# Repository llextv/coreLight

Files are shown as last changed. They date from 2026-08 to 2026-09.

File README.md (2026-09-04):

# CoreLight

CoreLight is an open-source DIY lighting controller built around an STM32H743.

The project is designed to manage stage lighting systems with up to **13 DMX universes**, Ethernet protocols such as **Art-Net and sACN**, timecode synchronization, show playback and system monitoring.

The goal is not to recreate a grandMA3 console. CoreLight is intended to be a hardware platform for a future open-source lighting-control system.

## Main features

- Up to 13 DMX outputs
- DMX512 and RS-485 communication
- Art-Net and sACN support
- Planned RDM support
- LTC and MTC timecode
- Show recording and playback
- Standalone operation
- DMX routing and merging
- Failover and redundancy
- Ethernet and OSC control
- Internal web interface
- Temperature, power and fan monitoring
- MicroSD and Flash storage
- USB-C for programming and updates
- RTC with battery backup
- Custom 4-layer PCB
- 3D-printed rack-mount enclosure

Most of these features are still under development. The current version should be considered a hardware prototype rather than a finished lighting controller.

---

## Architecture

The STM32H743 is the central processor of the system. It handles network communication, timecode, DMX processing, show playback and system monitoring.

The controller can also receive LTC, MTC and external event inputs. Lighting data is processed by the STM32 and sent to the required DMX outputs.

---

## Hardware

The current design uses the following main components:

| Component | Function |
|---|---|
| **STM32H743ZIT6** | Main microcontroller |
| **W5500** | Ethernet interface |
| **MAX3485** | DMX / RS-485 transceivers |
| **CD74HC4067M** | Signal routing and multiplexing |
| **IS42S16400J-7TL** | External SDRAM |
| **W25Q128JVSIQ** | SPI Flash |
| **DS3231M+** | Real-time clock |
| **INA226AIDGST** | Power monitoring |
| **TMP117AIDRVR** | Temperature monitoring |
| **SM712** | DMX transient protection |
| **USBLC6-2SC6** | USB ESD protection |

The complete component list is available in [BOM.csv](BOM.csv).

---

## Processing and memory

The STM32H743 was selected because the project requires more processing power and memory bandwidth than a basic microcontroller-based DMX interface.

It is responsible for:

- Art-Net, sACN and OSC communication
- DMX universe management
- RDM and DMX monitoring
- Show playback
- Timecode processing
- Failover logic
- Fan and thermal management
- System logs and diagnostics

### External SDRAM

The external SDRAM is used for temporary runtime data such as:

- DMX buffers
- Network packets
- Show playback data
- Large processing structures

### SPI Flash

The W25Q128JVSIQ Flash can be used for firmware, configuration and persistent system data.

### MicroSD card

The microSD card is intended for user-accessible files:

```text
/show
/config
/logs
/firmware
```

Shows, configuration files, logs and firmware updates can be stored on the card.

---

## DMX

CoreLight is designed to support up to **13 DMX universes**.

Each output uses a MAX3485 RS-485 transceiver and includes transient protection. A DMX universe contains up to 512 channels, giving a theoretical total of:

\[
13 \times 512 = 6656 \text{ DMX channels}
\]

Standard DMX wiring is used

The DMX data rate is 250 kbit/s.

Planned DMX features include:

- Flexible universe routing
- DMX repeater mode
- RDM
- DMX monitoring
- Signal-loss detection
- DMX merging and failover

For example, one network universe could be sent to several physical outputs

---

## Art-Net, sACN and Ethernet

Ethernet communication is handled by the W5500.

The network interface is intended to support:

- Art-Net
- sACN
- OSC
- Web-based configuration and monitoring

Network universes can be mapped to any of the physical DMX outputs instead of being permanently assigned to a single port.

---

## Timecode

CoreLight includes an LTC input and is designed to support MTC.

Timecode can be used to trigger lighting events or control show playback:

Example events could include scene changes, effect triggers or the start of a complete lighting sequence.

The RTC is used for system time, logs and scheduled events. It is separate from LTC, which is used for show synchronization.

---

## Standalone playback

A show can be uploaded to the microSD card and played back without a permanent computer connection.

A show file may contain:

- Scenes
- Cues
- DMX values
- Timing information
- Events
- Timecode positions

During playback, the STM32 loads the required data and generates the DMX output in real time.

---

## Failover and DMX merging

One of the main objectives is to improve system reliability during shows.

CoreLight is intended to detect problems such as:

- Loss of network data
- Software or hardware failure
- Missing DMX input
- Communication errors

Depending on the final firmware, the controller could switch to a backup source or continue playback using a locally stored show.

DMX merging is also planned, allowing several sources to contribute to the same output:

The merging rules and failover behavior are still being designed.

---

## Monitoring and cooling

The system includes temperature and power monitoring using a TMP117 and an INA226.

The firmware will be able to control the cooling fan and warn the user in case of excessive temperature or abnormal power consumption.

Available hardware includes:

- Temperature sensor
- Power monitor
- Fan output
- Status LEDs
- Buzzer

---

## Power supply

The controller is designed for a 24 V DC input.

The regulated voltages power the STM32, Ethernet interface, DMX transceivers, sensors and other logic circuits.

---

## User interface and web interface

The initial local interface consists of:

- Rotary encoder
- Push buttons
- Status LEDs
- Buzzer

A future web interface will provide access to:

- System status
- DMX monitoring
- Network settings
- Show management
- Logs
- Temperature and power data
- Firmware updates

The controller is intended to be configurable from a browser without requiring a dedicated screen.

Software link for the moment: 
https://www.qlcplus.org/download#

---

## PCB and enclosure

The PCB was designed in KiCad and uses four layers to simplify routing and provide dedicated ground and power planes.

The board contains:

- STM32H743
- External SDRAM
- SPI Flash
- Ethernet
- 13 DMX interfaces
- LTC input
- USB-C
- MicroSD
- RTC
- Power regulation
- Monitoring circuits
- User interface connections

The current design contains approximately 192 footprints.

The enclosure is a custom 3D-printed rack-mount case with openings for the DMX outputs, Ethernet, USB-C, LTC, power, fan and user controls.

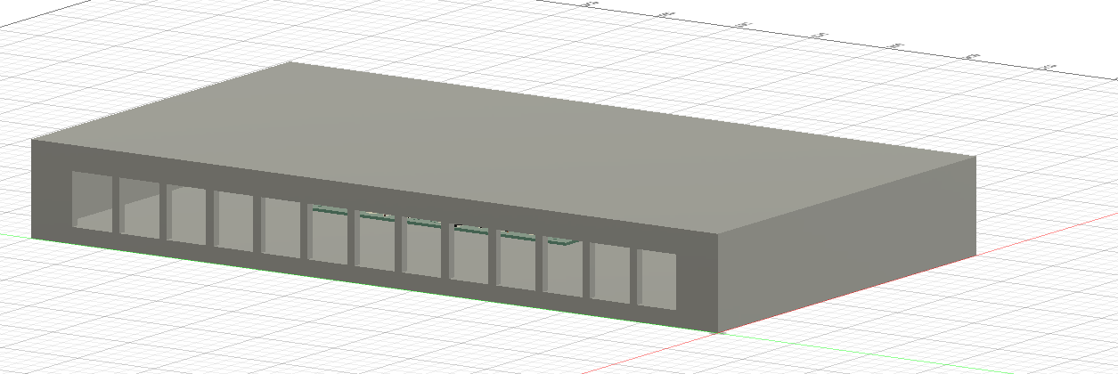
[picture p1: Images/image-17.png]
CoreLight enclosure


Assembly file: [coreLightAssembly.step](cad/coreLightAssembly.step)

CAD files are available in:

```text
/cad
```

The complete KiCad schematic is available in:

```text
/scheme
```
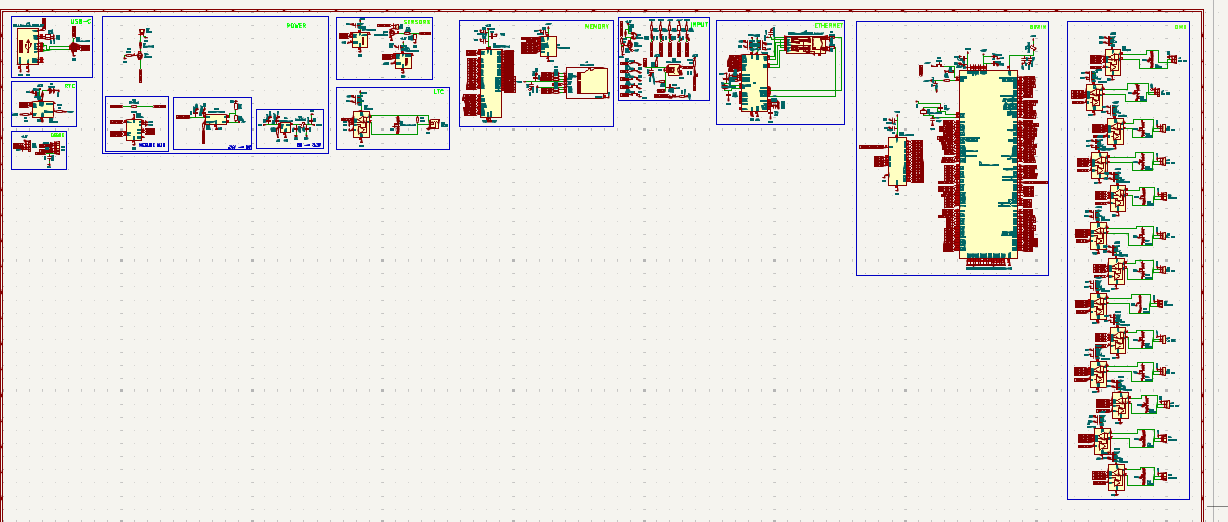
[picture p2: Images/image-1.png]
Scheme


---

## Estimated cost

The current estimate is:

```text
Components:  $66.01
PCB:         $36.99
Total:      ~$103 USD
```

This does not include shipping, assembly, enclosure parts or future design changes.

---

## Project journal

The development process is documented in [JOURNAL.md](JOURNAL.md).

It includes the PCB design, STM32CubeMX configuration, KiCad work, enclosure design, BOM creation and the problems encountered during development.

---

## Inspiration

CoreLight was inspired by professional lighting hardware such as the grandMA3 Processing Unit and Replay Unit.

The project is independent and is not affiliated with MA Lighting.

- [MA Lighting grandMA3 Processing Unit](https://www.malighting.com/product/grandma3-processing-unit-m-4010510/)
- [MA Lighting grandMA3 Replay Unit](https://www.malighting.com/product/grandma3-replay-unit-4010507/)

---

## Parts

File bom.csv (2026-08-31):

Category / Component | Manufacturer Part / Type | Quantity | Unit Price (USD) | Total Price (USD) | LCSC Link
Microcontroller | STM32H743ZIT6 | 1 | 15.50 | 15.50 | https://www.lcsc.com/category/941.html
Ethernet Controller | W5500 | 1 | 2.15 | 2.15 | https://www.lcsc.com/product-detail/C32843.html
DMX Transceiver | MAX3485ESA+ | 14 | 0.45 | 6.30 | https://www.lcsc.com/product-detail/C22447116.html
Multiplexer | CD74HC4067M | 1 | 0.32 | 0.32 | https://www.lcsc.com/product-detail/C496123.html
RTC | DS3231M+ | 1 | 1.80 | 1.80 | https://www.lcsc.com/product-detail/C1520508.html
SDRAM | IS42S16400J-7TL | 1 | 1.20 | 1.20 | https://www.lcsc.com/product-detail/C94865.html
SPI Flash | W25Q128JVSIQ | 1 | 0.75 | 0.75 | https://www.lcsc.com/product-detail/C113767.html
3.3V Regulator | AP2112K-3.3 | 1 | 0.22 | 0.22 | https://www.lcsc.com/product-detail/C23380830.html
5V Regulator | LM2596S-ADJ | 1 | 0.45 | 0.45 | https://www.lcsc.com/product-detail/C194351.html
Power Monitor | INA226AIDGST | 1 | 1.10 | 1.10 | https://www.lcsc.com/product-detail/C2653870.html
Temperature Sensor | TMP117AIDRVR | 1 | 1.40 | 1.40 | https://www.lcsc.com/product-detail/C699536.html
USB ESD Protection | USBLC6-2SC6 | 1 | 0.08 | 0.08 | https://www.lcsc.com/product-detail/C5261088.html
DMX TVS Protection | SM712 | 13 | 0.15 | 1.95 | https://www.lcsc.com/product-detail/C908219.html
Schottky Diode | 1N5819 | 1 | 0.03 | 0.03 | https://www.lcsc.com/product-detail/C2474.html
Switching Diode | 1N4148 | 1 | 0.01 | 0.01 | https://www.lcsc.com/product-detail/C49318123.html
Capacitor 100nF (0805) | 0805 X7R 50V 100nF | 33 | 0.005 | 0.17 | https://www.lcsc.com/product-detail/C49678.html
Capacitor 4.7µF (0805) | 0805 X5R 25V 4.7µF | 23 | 0.01 | 0.23 | https://www.lcsc.com/product-detail/C1779.html
Capacitor 22pF (0805) | 0805 C0G 50V 22pF | 4 | 0.005 | 0.02 | https://www.lcsc.com/product-detail/C1804.html
Resistor 10k (0805) | 0805 1% 1/8W 10k | 15 | 0.004 | 0.06 | https://www.lcsc.com/product-detail/C2907219.html
Resistor 330R (0805) | 0805 1% 1/8W 330R | 9 | 0.004 | 0.04 | https://www.lcsc.com/product-detail/C17630.html
Resistor 120R (0805) | 0805 1% 1/8W 120R | 1 | 0.004 | 0.004 | https://www.lcsc.com/product-detail/C17437.html
RJ45 Connector | HR911105A | 1 | 0.85 | 0.85 | https://www.lcsc.com/product-detail/C12074.html
MicroSD Connector | DM3D-SF | 1 | 0.30 | 0.30 | https://www.lcsc.com/product-detail/C719027.html
USB-C Connector | USB-C 16P (SMD) | 1 | 0.18 | 0.18 | https://www.lcsc.com/product-detail/C165948.html
24V Terminal Block | Phoenix 5.08mm 2P | 1 | 0.15 | 0.15 | https://www.lcsc.com/product-detail/C5183929.html
JST XH Connectors | JST-XH 2P/3P/4P/5P | 15 | 0.05 | 0.75 | https://www.lcsc.com/product-detail/C144394.html
3.5mm Audio Jack | Audio Jack 3.5mm (LTC) | 1 | 0.12 | 0.12 | https://www.lcsc.com/product-detail/C49284723.html
Rotary Encoder | EC11 with Switch | 1 | 0.25 | 0.25 | https://www.lcsc.com/product-detail/C2991196.html
Push Buttons | Tactile Switch 6x6mm | 6 | 0.03 | 0.18 | https://www.lcsc.com/product-detail/C7528752.html
Buzzer | Buzzer 3.3V | 1 | 0.10 | 0.10 | https://www.lcsc.com/product-detail/C252915.html
Battery Holder | CR2032 Battery Holder | 1 | 0.20 | 0.20 | https://www.lcsc.com/product-detail/C964792.html
Crystal Quartz | Crystal 25MHz (3225) | 2 | 0.08 | 0.16 | https://www.lcsc.com/product-detail/C9006.html
Transistor | 2N7002 | 1 | 0.011 | 0.011 | https://www.lcsc.com/product-detail/C916396.html
Resettable Fuse | 2920L500/30GR | 1 | 0.15 | 0.15 | https://www.lcsc.com/product-detail/C19078763.html

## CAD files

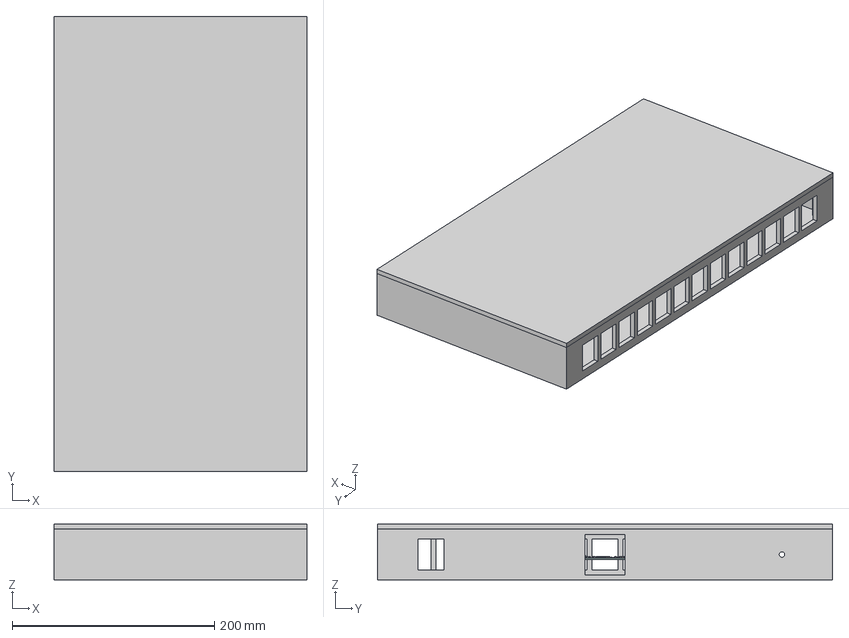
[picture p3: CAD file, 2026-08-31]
cad/coreLightAssembly.step
250.0 x 450.0 x 55.0 mm
D_DO-41_SOD81_P10.16mm_Horizontal_1
C_0805_2012Metric_1 x 69
R_0805_2012Metric_1 x 38
SOIC_8_39x49mm_P127mm x 14
JST_B3B_XH_A x 13
WSON_6_1EP_2x2mm_P065mm_EP1x16mm x 2
Keystone_3000_1x12mm
SOT_23_1 x 14
SOIC_24W_75x154mm_P127mm
JST_B4B_XH_A
Buzzer_12x95RM76
SOIC_16W_75x103mm_P127mm
SOT_23
LED_0805_2012Metric_1 x 7
microSD_HC_Hirose_DM3D-SF_1
VSSOP_10_3x3mm_P05mm
D_DO-35_SOD27_P7.62mm_Horizontal_1
TerminalBlock_Phoenix_MKDS_15_2_508_1x02_P508mm_Horizontal
Crystal_SMD_3225-4Pin_3.2x2.5mm_1 x 2
CQ assembly_1 x 2
CQ assembly
JST_B2B_XH_A
TSOP_II_54_222x1016mm_P08mm
JST_B5B_XH_A
LQFP_48_7x7mm_P05mm
SOT_23_5
SOT_23_6
coreLight_PCB
coreLightTop
coreLight

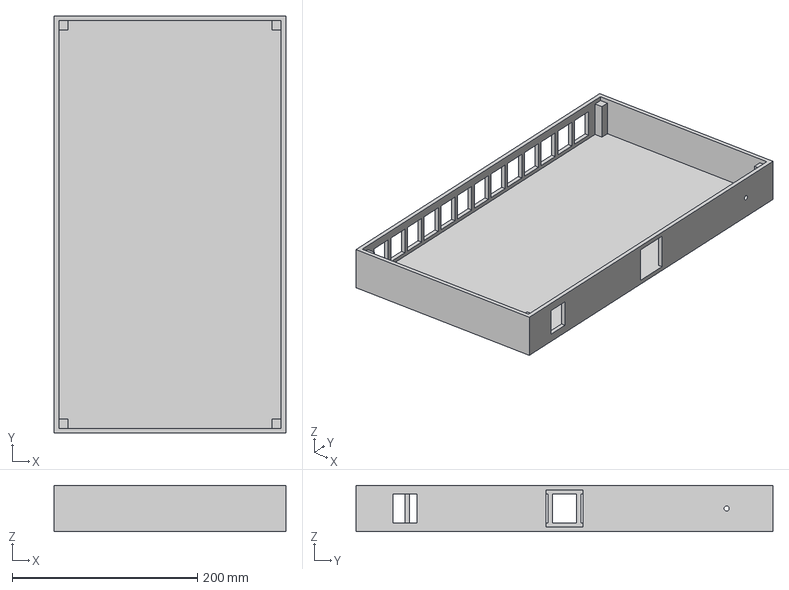
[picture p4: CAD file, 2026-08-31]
cad/coreLight.step
250.0 x 450.0 x 50.0 mm

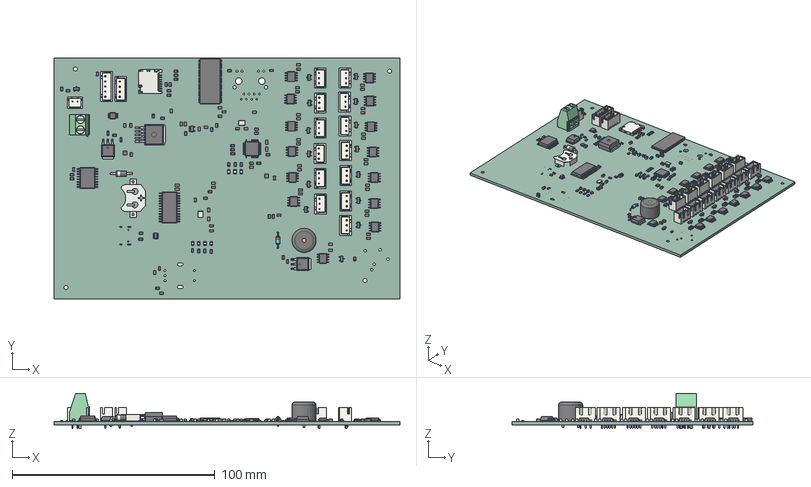
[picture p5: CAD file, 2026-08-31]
cad/coreLight_PCB.step
170.7 x 119.0 x 17.3 mm
D_DO-41_SOD81_P10.16mm_Horizontal_1
C_0805_2012Metric_1 x 69
R_0805_2012Metric_1 x 38
SOIC_8_39x49mm_P127mm x 14
JST_B3B_XH_A x 13
WSON_6_1EP_2x2mm_P065mm_EP1x16mm x 2
Keystone_3000_1x12mm
SOT_23_1 x 14
SOIC_24W_75x154mm_P127mm
JST_B4B_XH_A
Buzzer_12x95RM76
SOIC_16W_75x103mm_P127mm
SOT_23
LED_0805_2012Metric_1 x 7
microSD_HC_Hirose_DM3D-SF_1
VSSOP_10_3x3mm_P05mm
D_DO-35_SOD27_P7.62mm_Horizontal_1
TerminalBlock_Phoenix_MKDS_15_2_508_1x02_P508mm_Horizontal
Crystal_SMD_3225-4Pin_3.2x2.5mm_1 x 2
CQ assembly_1 x 2
CQ assembly
JST_B2B_XH_A
TSOP_II_54_222x1016mm_P08mm
JST_B5B_XH_A
LQFP_48_7x7mm_P05mm
SOT_23_5
SOT_23_6
coreLight_PCB

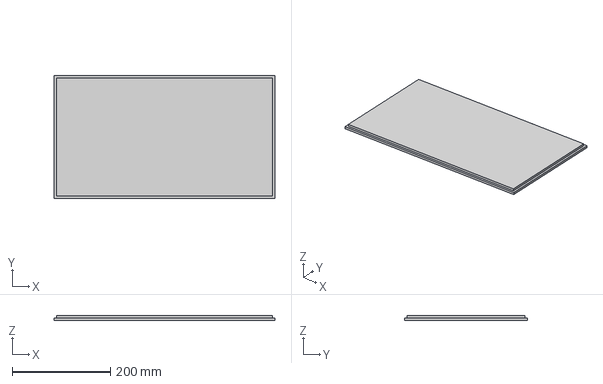
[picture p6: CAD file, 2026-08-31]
cad/coreLightTop.step
450.0 x 250.0 x 10.0 mm

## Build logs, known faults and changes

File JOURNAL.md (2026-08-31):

---
title: "CoreLight"
author: "llextv"
description: "My big project arround DMX / Stage effect management"
created_at: "2026-07-15"
---

# Day 1 & 2: Defining system & idea search & inspi
My initial plan was to build something resembling a lighting control unit like the grandMA3.
I need it to manage show lighting synchronized with audio (via LTC timecode) and capable of outputting up to 13 DMX universes.
For this project I need this:
- Calcul hearth & memory
  - SDRAM
  - Flash QSPI
  - STM32
  - RTC
- Alim & safety
  - 24V IN
  - Protection (fuse)
  - Régulation
  - Thermal management
- DMX Network
  - Ethernet (for ArtNet)
  - 13 DMX Output
  - LTC Timecode
- Storage
  - MicroSD (for soft and show lighting)
  - EC11 for navigate menues
  - Buzzer for heat alert
  - Status led
  - Heat capter
  - USB-C & JST for debug, prog / MAJ

For software Part:
- Artnet / sACN management
- RDM
- OSC
- Standalone mode
- Multiple sourced MTC / LTC
- EVENT management (with internal sensor)
- Failover
- DMX Fusion
- Monitoring DMX Cable
- Internal Web server
- Ventilation management
- Logs
- DMX Repeater & stock show

My inspiration & search:
https://www.malighting.com/product/grandma3-processing-unit-m-4010510/
https://www.malighting.com/product/grandma3-replay-unit-4010507/
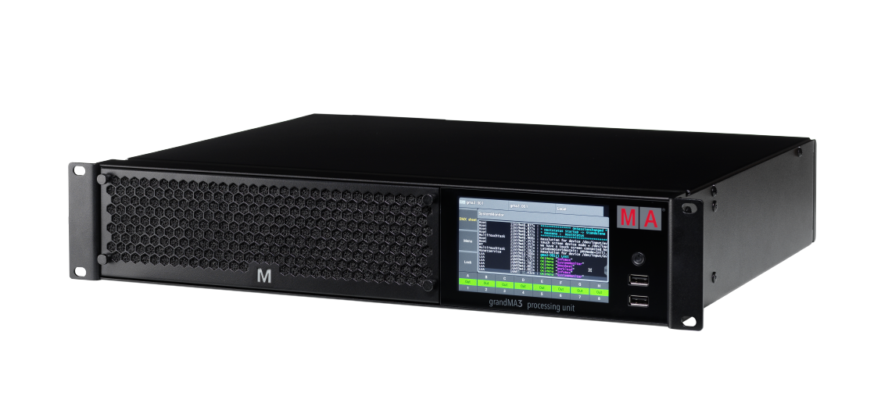
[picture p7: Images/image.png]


https://youtu.be/EvGTUB3FaL8?si=SulDiDoXiLldTTPZ
https://youtu.be/4lftq21JBpA?si=IHUjlWr8QZtvwl7I

And more other...

**Total time spent: 3 hours**

# Day 3: Find components for each functionnality

| **Component** | **Usage / Purpose** |
| --- | --- |
| **STM32H743ZIT6** | Main high-performance microcontroller (the "brain"). |
| **SDRAM** | External RAM for heavy real-time data buffering. |
| **QSPI Flash** | Non-volatile storage for firmware execution and code. |
| **W5500** | Ethernet interface for network lighting control (Art-Net/sACN). |
| **MAX3485** | RS-485 transceivers for DMX serial communication ports. |
| **CD74HC4067** | Multiplexer to expand and route multiple DMX channels. |
| **SM712 / TVS Diodes** | Surge and ESD protection for data lines. |
| **24V In & Fuse** | Main power input and overcurrent protection. |
| **MOSFET (Power / 2N7002)** | Switching control for the cooling fan and loads. |
| **MicroSD Card** | Storage for show files, logs, and configurations. |
| **EC11 Rotary Encoder** | User interface wheel for menu navigation. |
| **Buzzer & LEDs** | Audio alerts and status indicators. |
| **RTC & CR2032 Battery** | Real-time clock backup for precise event timestamps. |
| **I2C Temp Sensors** | Thermal monitoring of the board. |
| **Crystal 25MHz** | External clock source for high-speed MCU timing. |
| **USB-C Receptacle** | Programming, debugging, and power connection. |

With all of theses components, I had a good starting point to begin designing in KiCad.
But I had forgotten that finding the perfect part for the project in KiCad is very complicated, so I had to modify certain components and tweak the footprints to get everything working.
I spent a lot of time installing the necessary libraries—such as the JLCPCB one, or even the STM32 library, which wasn't included in my KiCad installation.
I watched this video that explains how to do it: https://youtu.be/DhJCy-LbRto?si=LvXneZgDRm5MqSkQ
I then placed my components and grouped them by function:
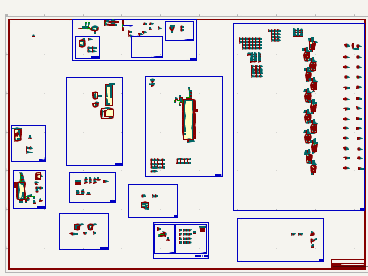
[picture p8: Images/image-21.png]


**Total time spent: 3 hours**

# Day 4: Discover STM32CubeMX
That’s where I hit a wall: how do you use an STM32 and figure out its pinout? I had no idea, so I asked an AI; it pointed me toward a piece of software called STM32CubeMX. I downloaded it and stepped into a murky world where every setting I tweaked seemed to break everything I was doing.
To arrive at a working version, I had to create about eight alternative versions—breaking things and having to start over each time—because I didn't understand the software at all, even with the AI helping me locate the menus...
I literally spent four hours on this pinout, and I really hope I won't have to do it again—it's a nightmare lol.
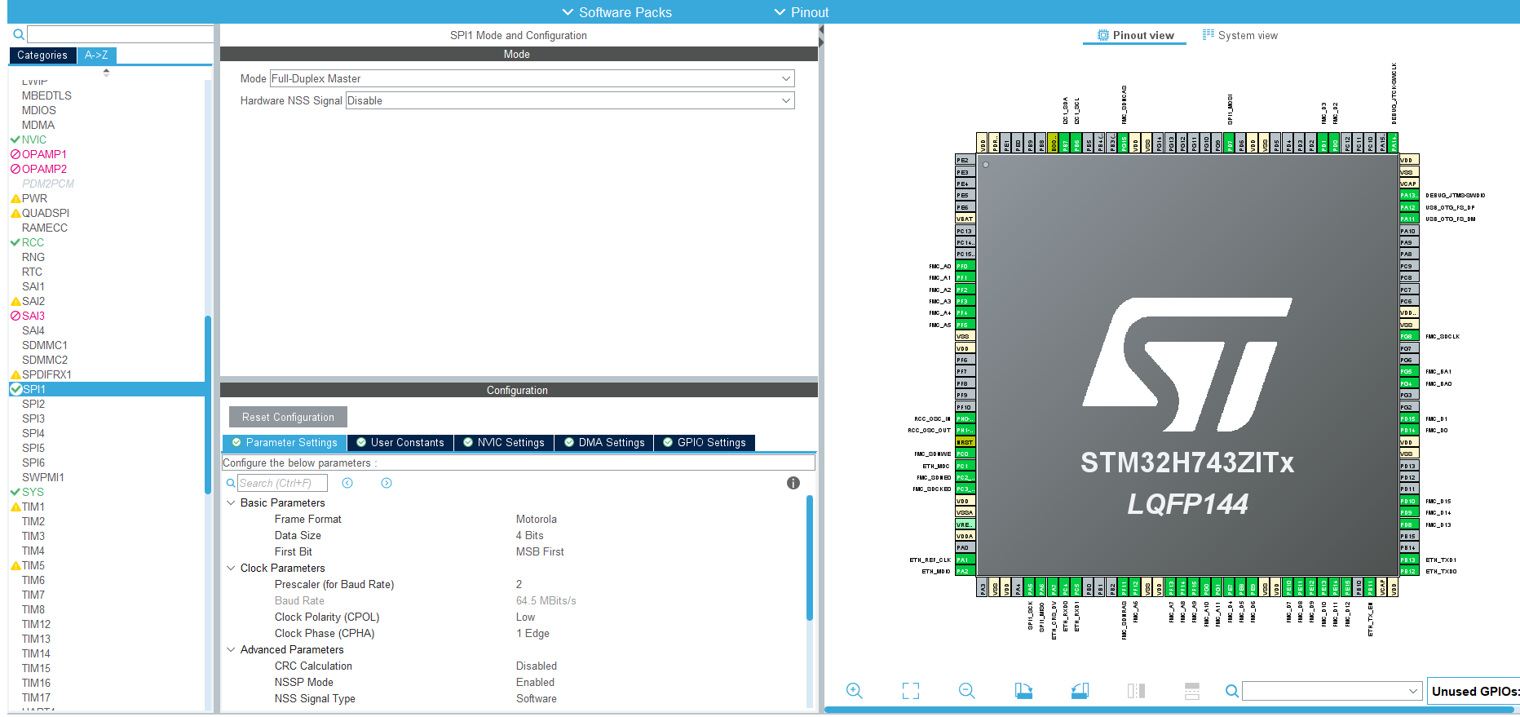
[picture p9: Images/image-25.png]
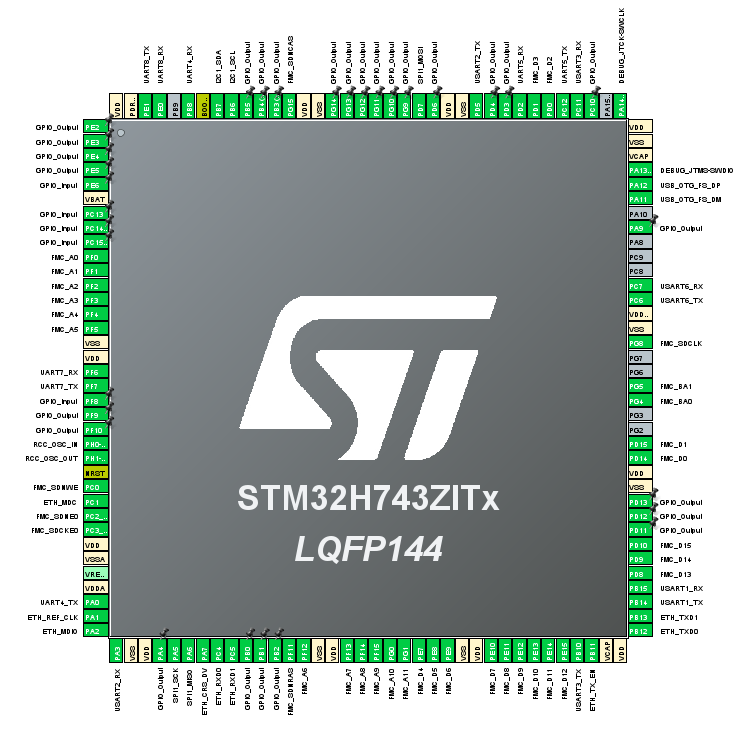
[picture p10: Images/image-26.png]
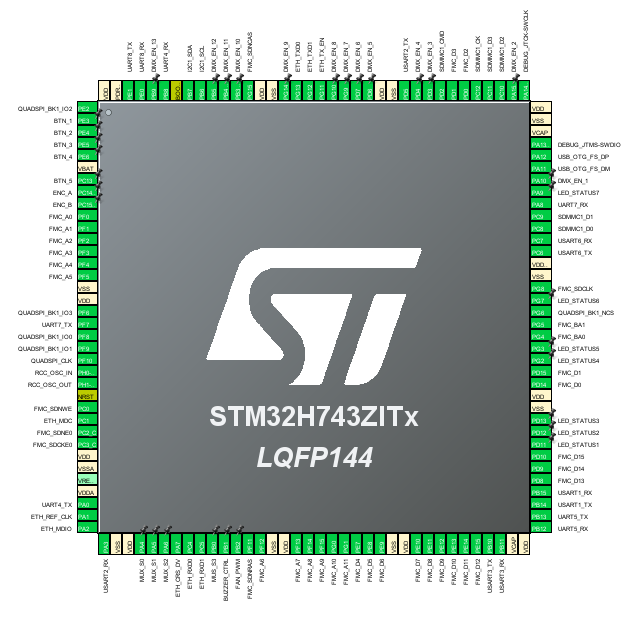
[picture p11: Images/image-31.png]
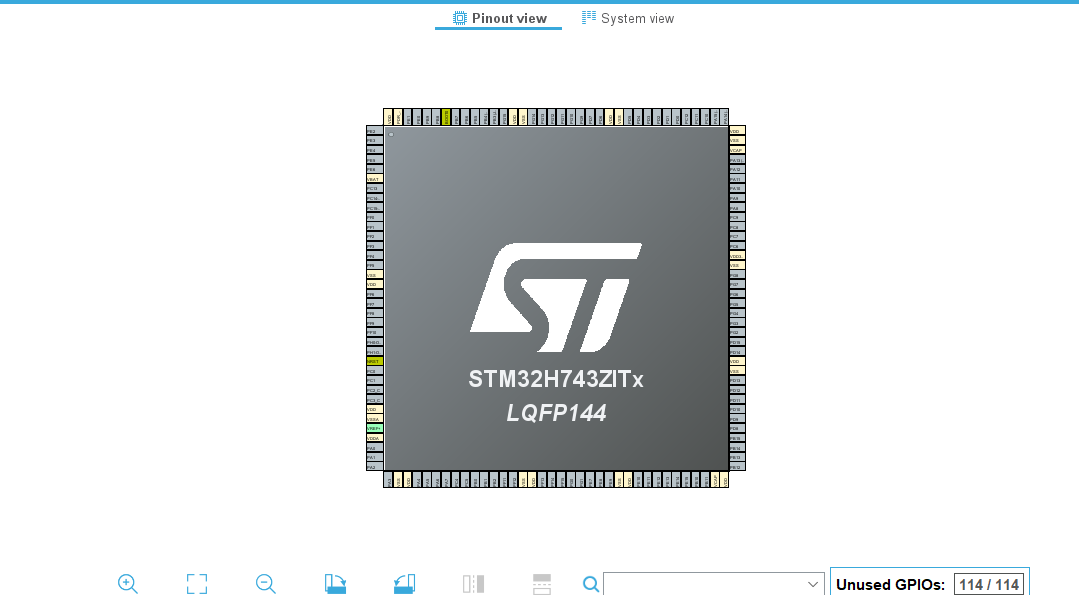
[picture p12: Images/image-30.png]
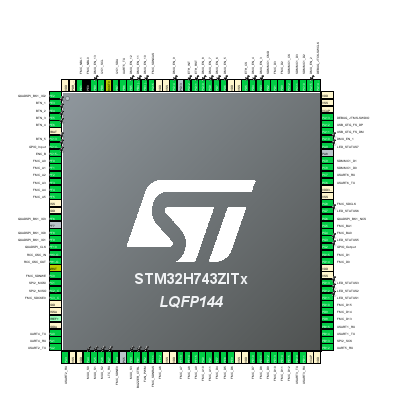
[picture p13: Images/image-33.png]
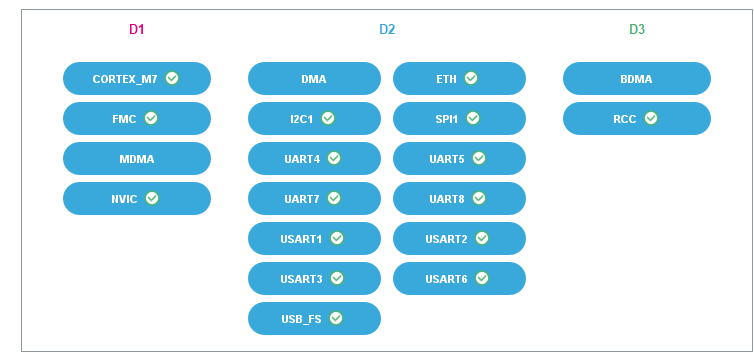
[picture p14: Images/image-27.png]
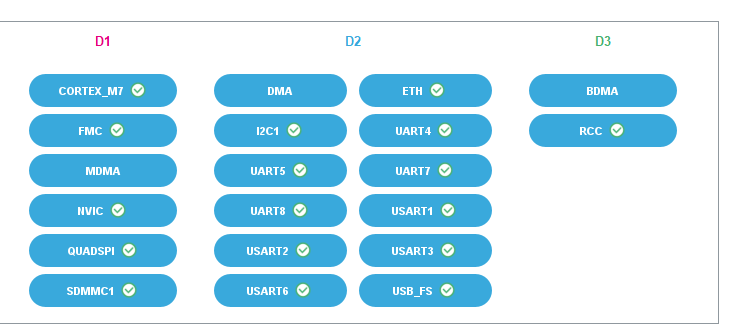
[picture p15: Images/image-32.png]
      
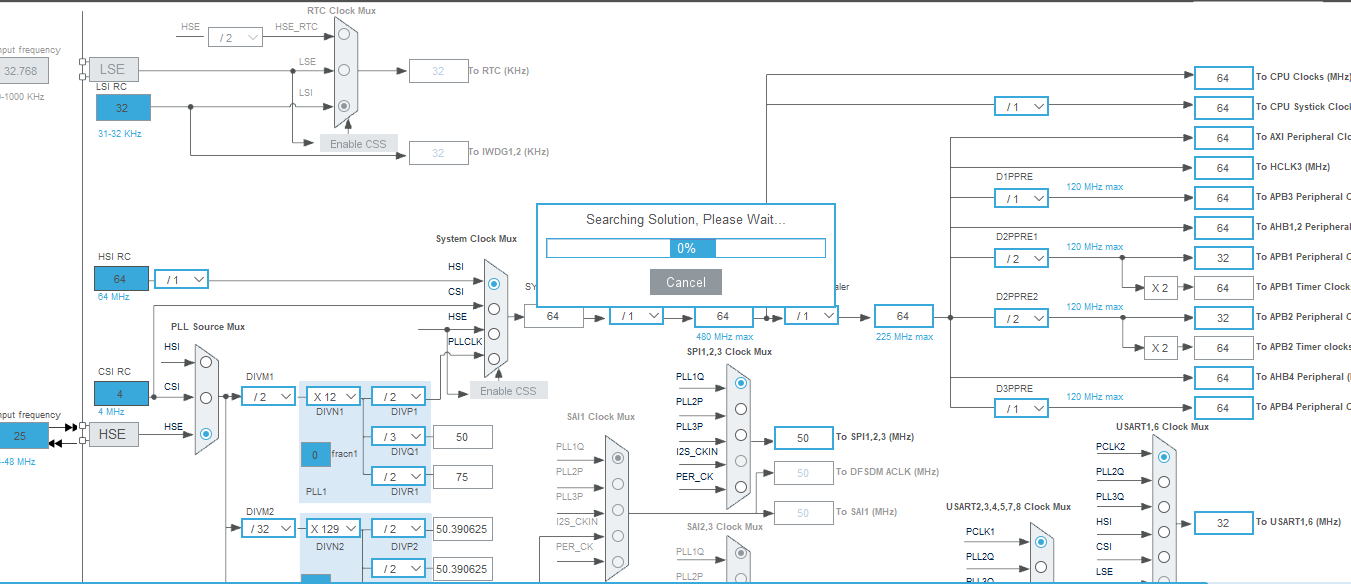
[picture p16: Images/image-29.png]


Above, for example, you can see two versions I took screenshots of (the one I had the most hope for).

**Total time spent: 4.5 hours**

# Day 5: Cabling all on KiCad (Part1)
I calmly started wiring everything up on KiCad, thinking it wouldn't take much time.
Unaware that I was

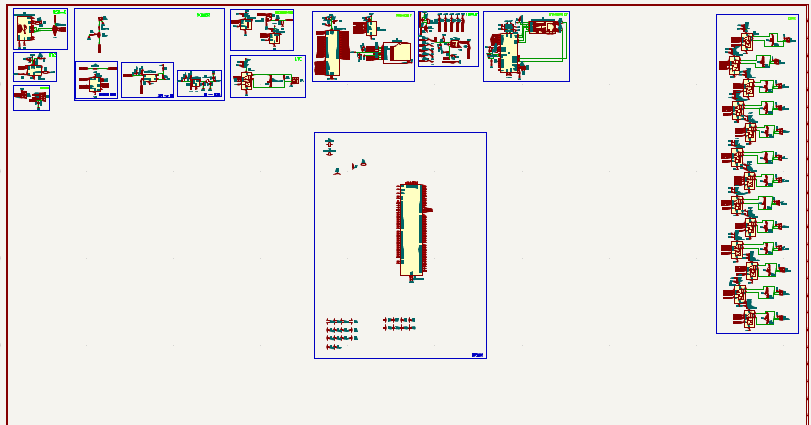
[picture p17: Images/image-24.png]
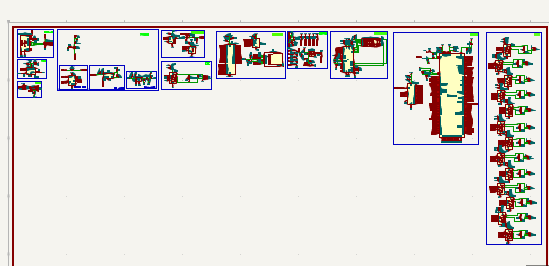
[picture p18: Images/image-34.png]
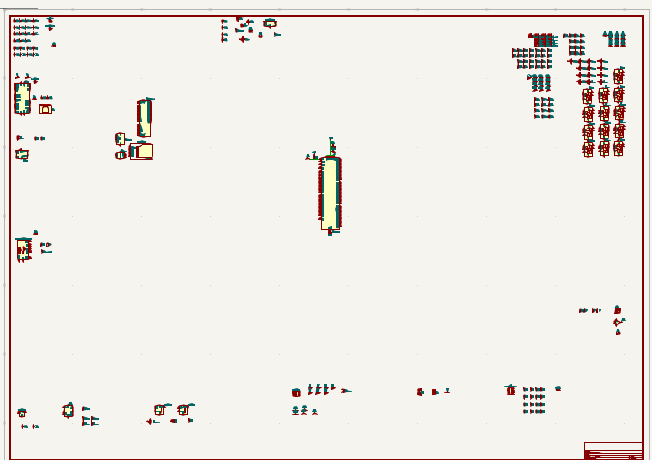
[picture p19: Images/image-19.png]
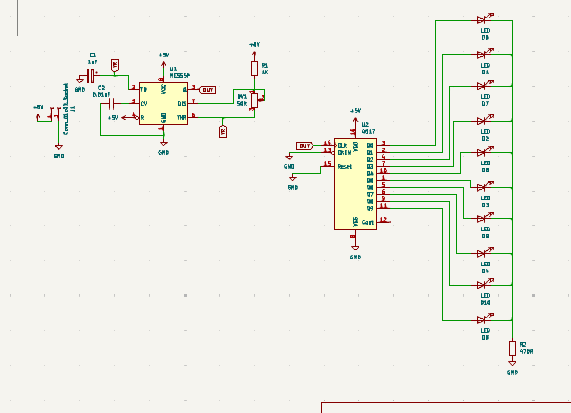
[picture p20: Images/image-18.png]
    

That’s five hours spent on Day One of the wiring—starting the job, only to keep having to redo it.

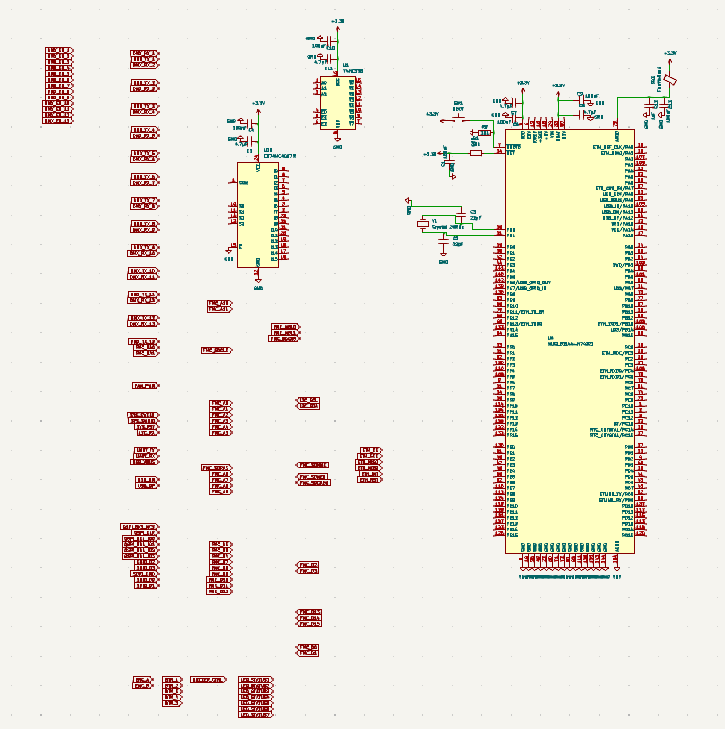
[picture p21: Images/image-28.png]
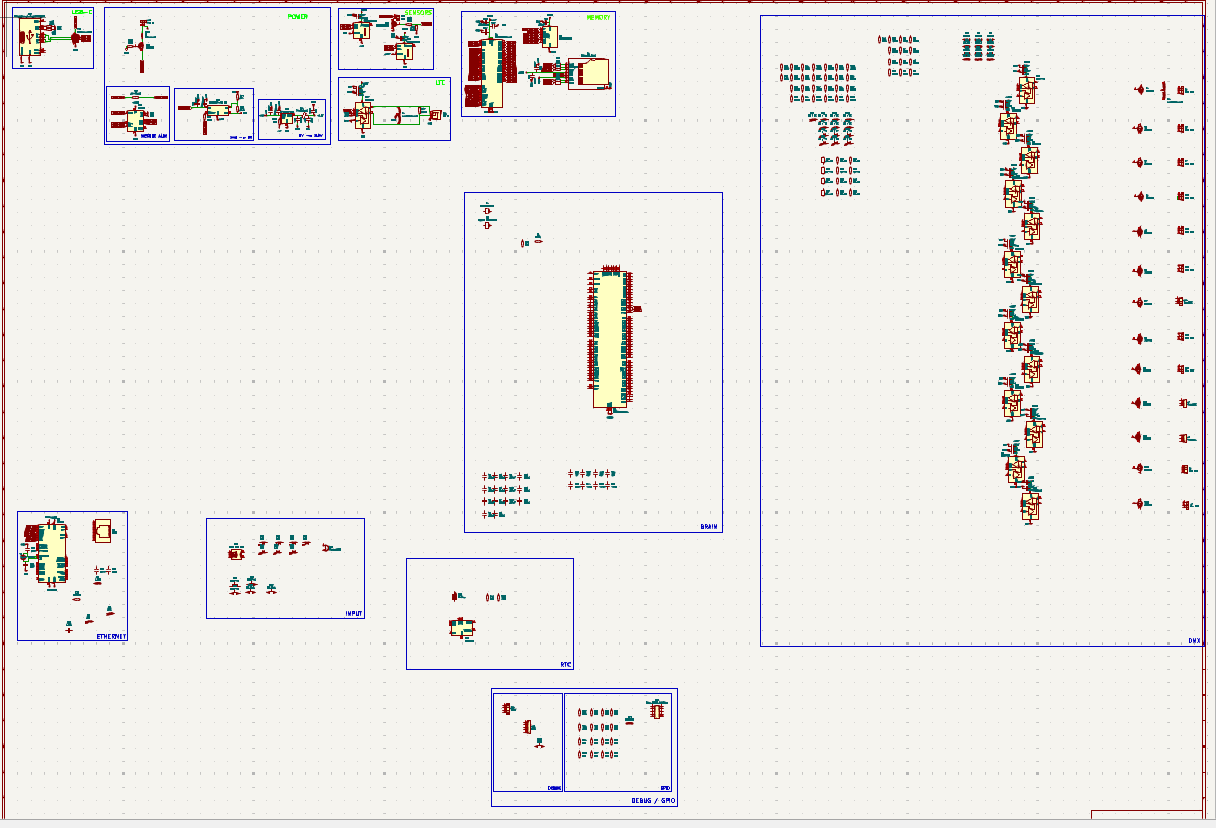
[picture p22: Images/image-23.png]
 

**Total time spent: 5 hours**

# Day 6: Cabling all on KiCad (Part2)
Right, after starting this wiring job, I took a day off, and here I am on day 6.

I decided to finish the schematic today so I can start the fun part—the PCB—tomorrow.
So that's what I did. (Just a reminder that my electronics knowledge is limited to the ESP32 ^^)

Before: 

After: 
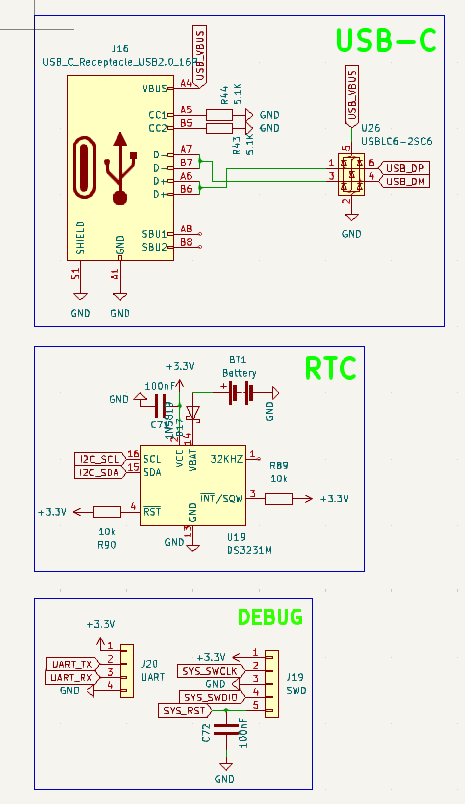
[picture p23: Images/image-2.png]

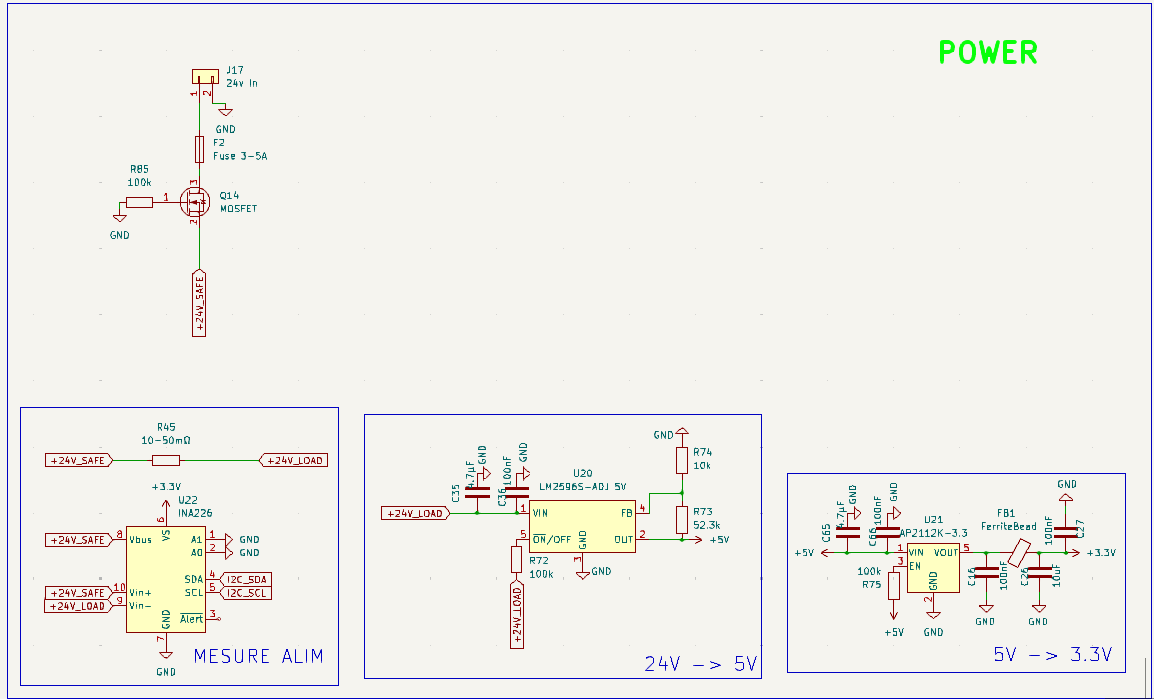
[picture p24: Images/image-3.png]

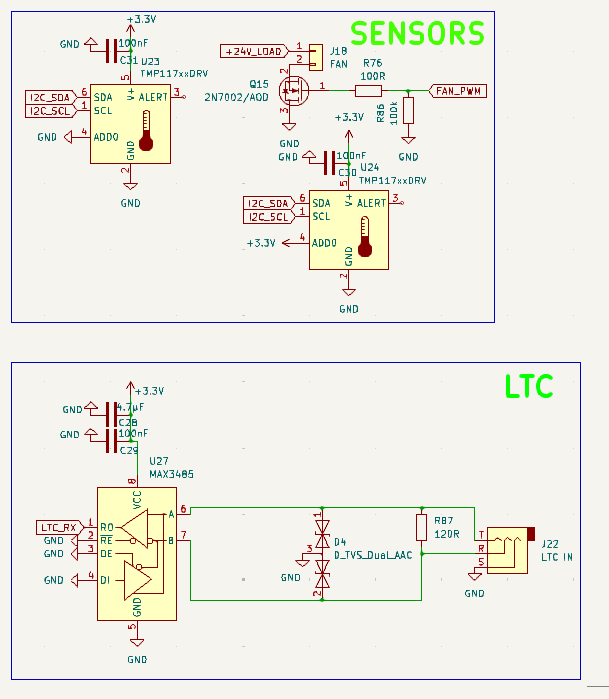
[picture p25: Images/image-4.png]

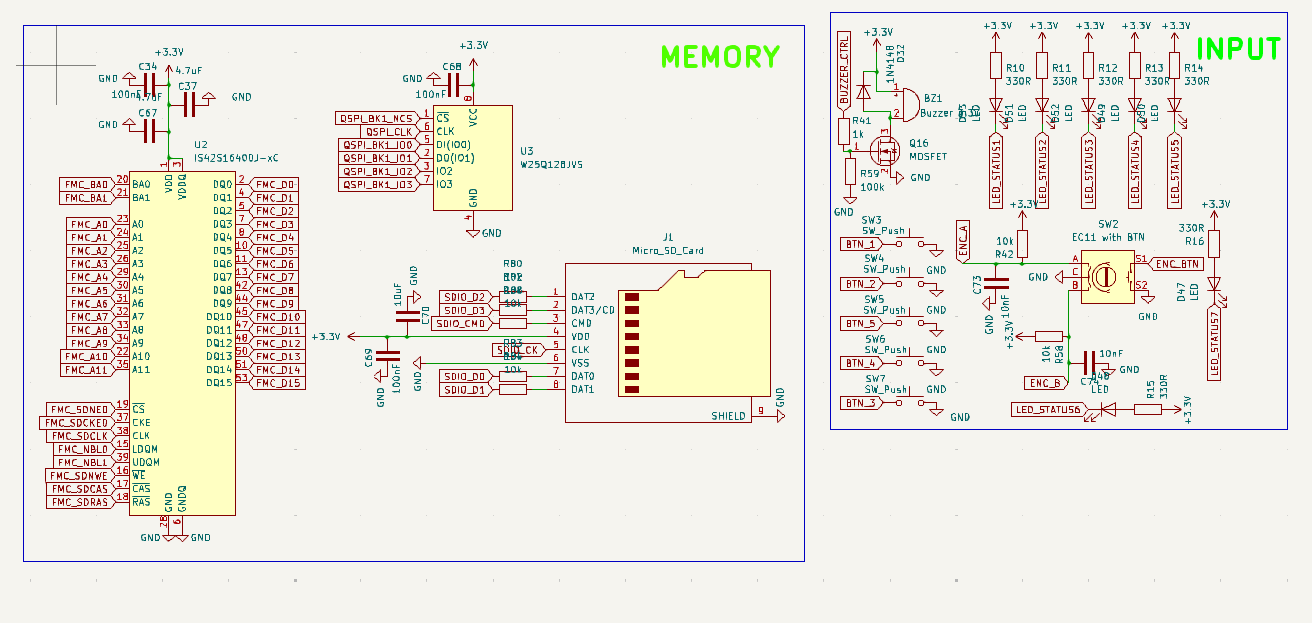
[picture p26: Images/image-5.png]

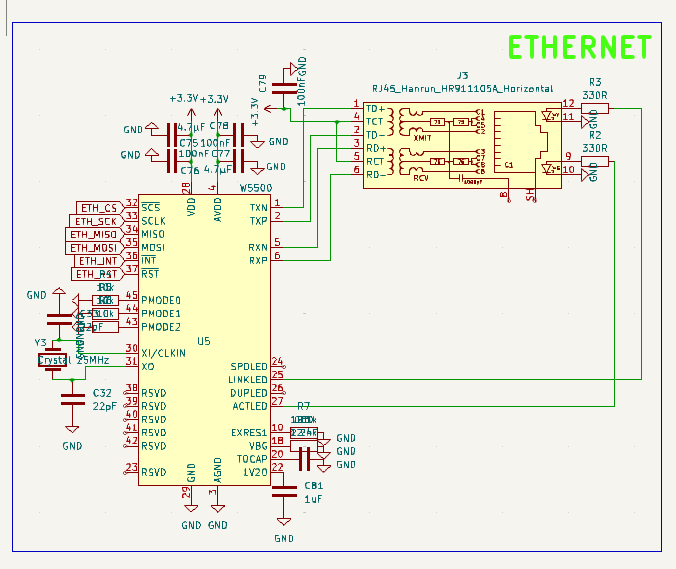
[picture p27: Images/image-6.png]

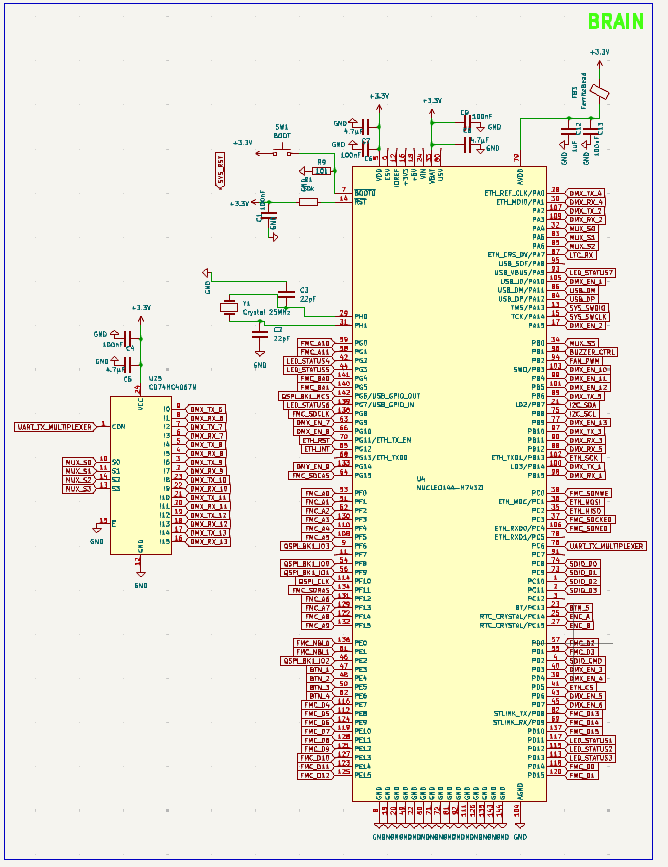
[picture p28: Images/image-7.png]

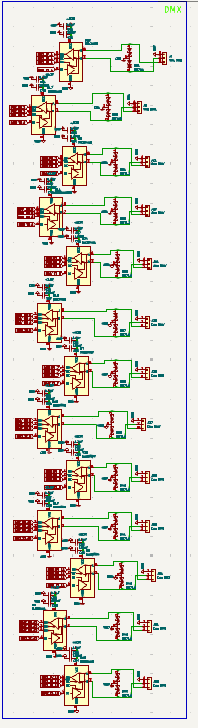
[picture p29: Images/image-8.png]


It’s so beautiful and satisfying when it’s finished and passes the ERC.

**Total time spent: 6 hours**

# Day 7: PCB Routing -> Bets Part ...or not
Okay, I woke up excited and eager to do my PCB routing, since I saw it as something quick and simple (bearing in mind that my PCB experience is limited to connecting LEDs to an ESP); so I open my software, but...
I had overlooked a small part of the job—assigning the footprints and schematics—so I spent 45 min properly defining everything (since, as the AI mentioned, this might be the most critical part of the project).
192 fingerprints to assign

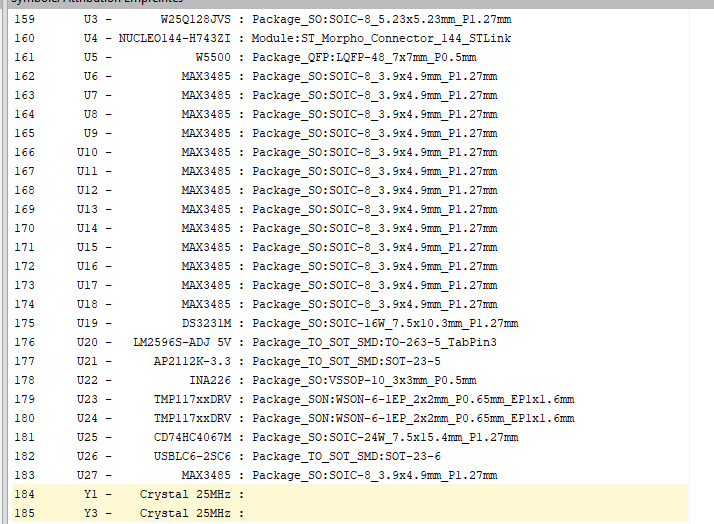
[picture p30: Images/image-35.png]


Then I started the routing, intending to do everything on two layers.
And then I thought to myself that doing it in two layers might be a bit more complicated than expected.
Anyway, I’ve repositioned all my components—especially the power supply decoupling capacitors—because, for some reason, KiCad wasn't managing to connect them right next to the pins...

Before:
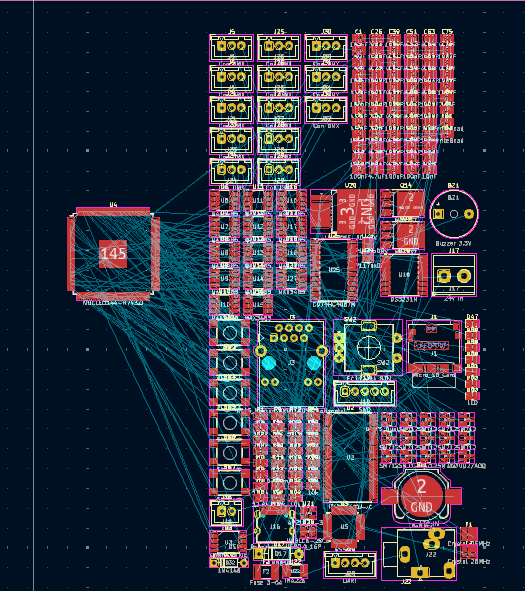
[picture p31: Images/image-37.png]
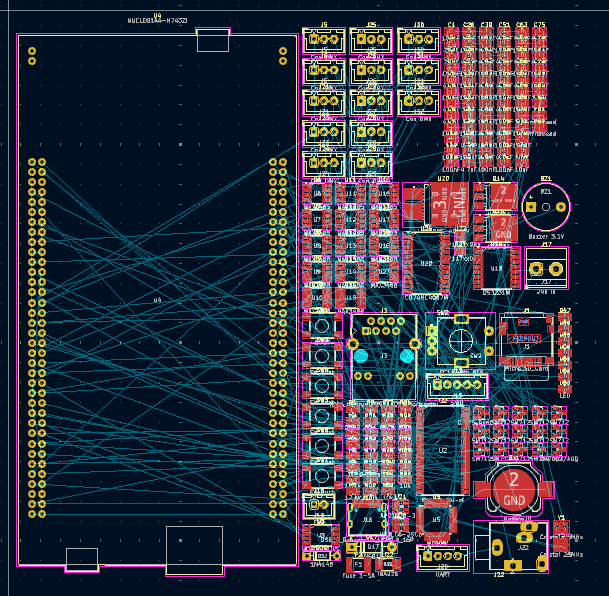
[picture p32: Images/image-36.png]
 

After:
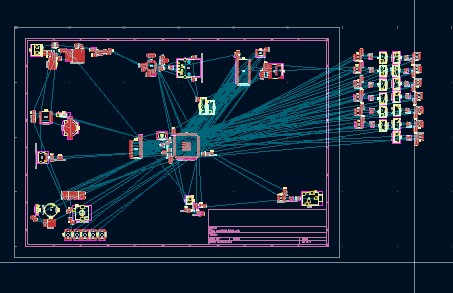
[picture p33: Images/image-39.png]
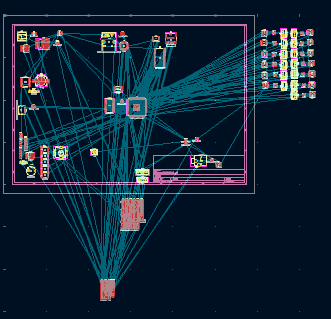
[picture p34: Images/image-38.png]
 

So, I started wiring up the power supplies and components:
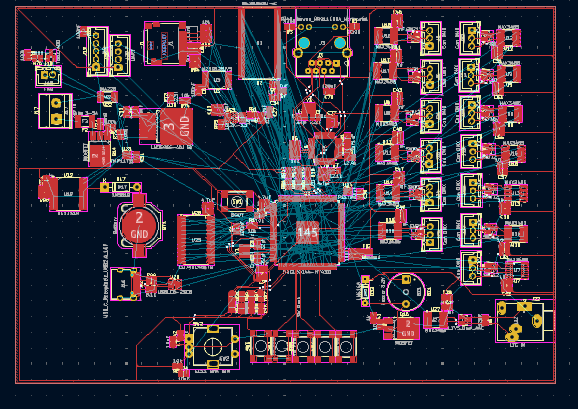
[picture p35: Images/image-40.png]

It wasn't as simple as I thought, because I was still working with a 2-layer design, with one layer dedicated to GND.
I've finished almost all the connections, except for the one to the STM32.

**Total time spent: 5 hours**

# Day 8: Routing STM32
The hardest part has begun.
It was a real battlefield, and fortunately, at one point I decided to go with a 4-layer PCB after getting a quote from JLCPCB to check the budget.

Here is state of the PCB before:
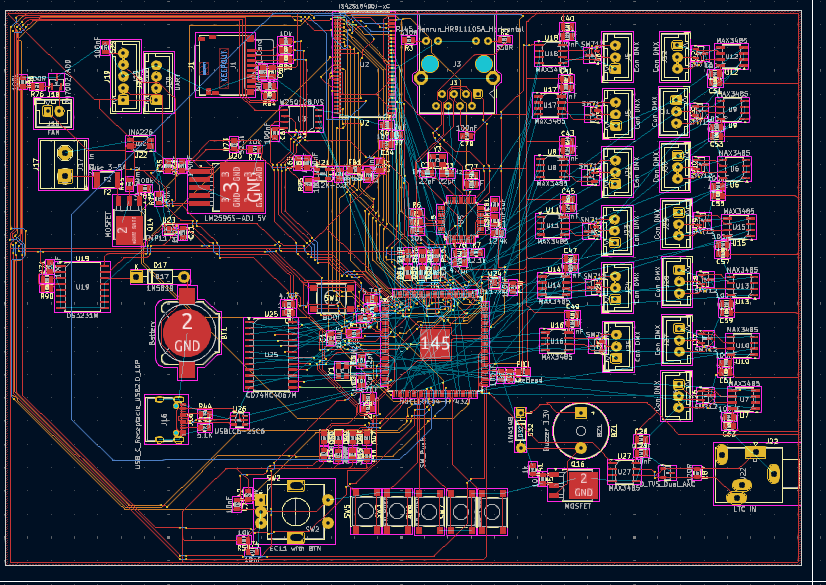
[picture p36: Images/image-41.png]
  
and after:
    

I love the final 3D result.
Anyway, I exported the PCB... and posted a message on the Forge Help forum to get it reviewed and check for any issues—which honestly wouldn't surprise me at all, given the late hours I was working on it. Lol.
I'll need to remember to add some text to it before having it made !!

**Total time spent: 6 hours**

# Day 9: Estimation

I have made on JLCPCB an estimation
Now I need to think about the software and the 3D printing needed to make it stand (I imagine it a bit like a 3D server rack, so I'm going to try something like that).
Today, I just took a quick look at PCB prices... but I also did a lot of rewording on my JOURNAL.md file using Google Translate to tidy things up.

**Total time spent: 0.5 hours**

# Day 10: Starting KiCad
Import PCB in Kicad


I starting create box:


I made box to be rackable if possible

Made hole for USB-C & LTC IN


**Total time spent: 0.75 hours**

# Day 11: We continue work
No response on forum to check my card :(
I also re-send another demand ...

So I continue to work on CAD file:

Adding fan hole


Removing top and add for screw top 


Make top


Make assembly


**Total time spent: 1.5 hours**

# Day 12: Make BOM

I start to search each reference on LSCS:

I made it in CSV:
Category / Component,Manufacturer Part / Type,Quantity,Unit Price (USD),Total Price (USD),LCSC Link
Microcontroller,STM32H743ZIT6,1,15.50,15.50,https://www.lcsc.com/category/941.html
Ethernet Controller,W5500,1,2.15,2.15,https://www.lcsc.com/product-detail/C32843.html
DMX Transceiver,MAX3485ESA+,14,0.45,6.30,https://www.lcsc.com/product-detail/C22447116.html
Multiplexer,CD74HC4067M,1,0.32,0.32,https://www.lcsc.com/product-detail/C496123.html
RTC,DS3231M+,1,1.80,1.80,https://www.lcsc.com/product-detail/C1520508.html
SDRAM,IS42S16400J-7TL,1,1.20,1.20,https://www.lcsc.com/product-detail/C94865.html
SPI Flash,W25Q128JVSIQ,1,0.75,0.75,https://www.lcsc.com/product-detail/C113767.html
3.3V Regulator,AP2112K-3.3,1,0.22,0.22,https://www.lcsc.com/product-detail/C23380830.html
5V Regulator,LM2596S-ADJ,1,0.45,0.45,https://www.lcsc.com/product-detail/C194351.html
Power Monitor,INA226AIDGST,1,1.10,1.10,https://www.lcsc.com/product-detail/C2653870.html
Temperature Sensor,TMP117AIDRVR,1,1.40,1.40,https://www.lcsc.com/product-detail/C699536.html
USB ESD Protection,USBLC6-2SC6,1,0.08,0.08,https://www.lcsc.com/product-detail/C5261088.html
DMX TVS Protection,SM712,13,0.15,1.95,https://www.lcsc.com/product-detail/C908219.html
Schottky Diode,1N5819,1,0.03,0.03,https://www.lcsc.com/product-detail/C2474.html
Switching Diode,1N4148,1,0.01,0.01,https://www.lcsc.com/product-detail/C49318123.html
Capacitor 100nF (0805),0805 X7R 50V 100nF,33,0.005,0.17,https://www.lcsc.com/product-detail/C49678.html
Capacitor 4.7µF (0805),0805 X5R 25V 4.7µF,23,0.01,0.23,https://www.lcsc.com/product-detail/C1779.html
Capacitor 22pF (0805),0805 C0G 50V 22pF,4,0.005,0.02,https://www.lcsc.com/product-detail/C1804.html
Resistor 10k (0805),0805 1% 1/8W 10k,15,0.004,0.06,https://www.lcsc.com/product-detail/C2907219.html
Resistor 330R (0805),0805 1% 1/8W 330R,9,0.004,0.04,https://www.lcsc.com/product-detail/C17630.html
Resistor 120R (0805),0805 1% 1/8W 120R,1,0.004,0.004,https://www.lcsc.com/product-detail/C17437.html
RJ45 Connector,HR911105A,1,0.85,0.85,https://www.lcsc.com/product-detail/C12074.html
MicroSD Connector,DM3D-SF,1,0.30,0.30,https://www.lcsc.com/product-detail/C719027.html
USB-C Connector,USB-C 16P (SMD),1,0.18,0.18,https://www.lcsc.com/product-detail/C165948.html
24V Terminal Block,Phoenix 5.08mm 2P,1,0.15,0.15,https://www.lcsc.com/product-detail/C5183929.html
JST XH Connectors,JST-XH 2P/3P/4P/5P,15,0.05,0.75,https://www.lcsc.com/product-detail/C144394.html
3.5mm Audio Jack,Audio Jack 3.5mm (LTC),1,0.12,0.12,https://www.lcsc.com/product-detail/C49284723.html
Rotary Encoder,EC11 with Switch,1,0.25,0.25,https://www.lcsc.com/product-detail/C2991196.html
Push Buttons,Tactile Switch 6x6mm,6,0.03,0.18,https://www.lcsc.com/product-detail/C7528752.html
Buzzer,Buzzer 3.3V,1,0.10,0.10,https://www.lcsc.com/product-detail/C252915.html
Battery Holder,CR2032 Battery Holder,1,0.20,0.20,https://www.lcsc.com/product-detail/C964792.html
Crystal Quartz,Crystal 25MHz (3225),2,0.08,0.16,https://www.lcsc.com/product-detail/C9006.html
Transistor,2N7002,1,0.011,0.011,https://www.lcsc.com/product-detail/C916396.html
Resettable Fuse,2920L500/30GR,1,0.15,0.15,https://www.lcsc.com/product-detail/C19078763.html

in markdown:
| Category / Component | Manufacturer Part / Type | Quantity | Unit Price (USD) | Total Price (USD) | LCSC Link |
| :--- | :--- | :--- | :--- | :--- | :--- |
| **Microcontroller** | STM32H743ZIT6 | 1 | $15.50 | $15.50 | [Link](https://www.lcsc.com/category/941.html) |
| **Ethernet Controller** | W5500 | 1 | $2.15 | $2.15 | [Link](https://www.lcsc.com/product-detail/C32843.html) |
| **DMX Transceiver** | MAX3485ESA+ | 14 | $0.45 | $6.30 | [Link](https://www.lcsc.com/product-detail/C22447116.html) |
| **Multiplexer** | CD74HC4067M | 1 | $0.32 | $0.32 | [Link](https://www.lcsc.com/product-detail/C496123.html) |
| **RTC** | DS3231M+ | 1 | $1.80 | $1.80 | [Link](https://www.lcsc.com/product-detail/C1520508.html) |
| **SDRAM** | IS42S16400J-7TL | 1 | $1.20 | $1.20 | [Link](https://www.lcsc.com/product-detail/C94865.html) |
| **SPI Flash** | W25Q128JVSIQ | 1 | $0.75 | $0.75 | [Link](https://www.lcsc.com/product-detail/C113767.html) |
| **3.3V Regulator** | AP2112K-3.3 | 1 | $0.22 | $0.22 | [Link](https://www.lcsc.com/product-detail/C23380830.html) |
| **5V Regulator** | LM2596S-ADJ | 1 | $0.45 | $0.45 | [Link](https://www.lcsc.com/product-detail/C194351.html) |
| **Power Monitor** | INA226AIDGST | 1 | $1.10 | $1.10 | [Link](https://www.lcsc.com/product-detail/C2653870.html) |
| **Temperature Sensor** | TMP117AIDRVR | 1 | $1.40 | $1.40 | [Link](https://www.lcsc.com/product-detail/C699536.html) |
| **USB ESD Protection** | USBLC6-2SC6 | 1 | $0.08 | $0.08 | [Link](https://www.lcsc.com/product-detail/C5261088.html) |
| **DMX TVS Protection** | SM712 | 13 | $0.15 | $1.95 | [Link](https://www.lcsc.com/product-detail/C908219.html) |
| **Schottky Diode** | 1N5819 | 1 | $0.03 | $0.03 | [Link](https://www.lcsc.com/product-detail/C2474.html) |
| **Switching Diode** | 1N4148 | 1 | $0.01 | $0.01 | [Link](https://www.lcsc.com/product-detail/C49318123.html) |
| **Capacitor 100nF (0805)** | 0805 X7R 50V 100nF | 33 | $0.005 | $0.17 | [Link](https://www.lcsc.com/product-detail/C49678.html) |
| **Capacitor 4.7µF (0805)** | 0805 X5R 25V 4.7µF | 23 | $0.01 | $0.23 | [Link](https://www.lcsc.com/product-detail/C1779.html) |
| **Capacitor 22pF (0805)** | 0805 C0G 50V 22pF | 4 | $0.005 | $0.02 | [Link](https://www.lcsc.com/product-detail/C1804.html) |
| **Resistor 10k (0805)** | 0805 1% 1/8W 10k | 15 | $0.004 | $0.06 | [Link](https://www.lcsc.com/product-detail/C2907219.html) |
| **Resistor 330R (0805)** | 0805 1% 1/8W 330R | 9 | $0.004 | $0.04 | [Link](https://www.lcsc.com/product-detail/C17630.html) |
| **Resistor 120R (0805)** | 0805 1% 1/8W 120R | 1 | $0.004 | $0.004 | [Link](https://www.lcsc.com/product-detail/C17437.html) |
| **RJ45 Connector** | HR911105A | 1 | $0.85 | $0.85 | [Link](https://www.lcsc.com/product-detail/C12074.html) |
| **MicroSD Connector** | DM3D-SF | 1 | $0.30 | $0.30 | [Link](https://www.lcsc.com/product-detail/C719027.html) |
| **USB-C Connector** | USB-C 16P (SMD) | 1 | $0.18 | $0.18 | [Link](https://www.lcsc.com/product-detail/C165948.html) |
| **24V Terminal Block** | Phoenix 5.08mm 2P | 1 | $0.15 | $0.15 | [Link](https://www.lcsc.com/product-detail/C5183929.html) |
| **JST XH Connectors** | JST-XH 2P/3P/4P/5P | 15 | $0.05 | $0.75 | [Link](https://www.lcsc.com/product-detail/C144394.html) |
| **3.5mm Audio Jack** | Audio Jack 3.5mm (LTC) | 1 | $0.12 | $0.12 | [Link](https://www.lcsc.com/product-detail/C49284723.html) |
| **Rotary Encoder** | EC11 with Switch | 1 | $0.25 | $0.25 | [Link](https://www.lcsc.com/product-detail/C2991196.html) |
| **Push Buttons** | Tactile Switch 6x6mm | 6 | $0.03 | $0.18 | [Link](https://www.lcsc.com/product-detail/C7528752.html) |
| **Buzzer** | Buzzer 3.3V | 1 | $0.10 | $0.10 | [Link](https://www.lcsc.com/product-detail/C252915.html) |
| **Battery Holder** | CR2032 Battery Holder | 1 | $0.20 | $0.20 | [Link](https://www.lcsc.com/product-detail/C964792.html) |
| **Crystal Quartz** | Crystal 25MHz (3225) | 2 | $0.08 | $0.16 | [Link](https://www.lcsc.com/product-detail/C9006.html) |
| **Transistor** | 2N7002 | 1 | $0.011 | $0.011 | [Link](https://www.lcsc.com/product-detail/C916396.html) |
| **Resettable Fuse** | 2920L500/30GR | 1 | $0.15 | $0.15 | [Link](https://www.lcsc.com/product-detail/C19078763.html) |

==> 66.01$ of component + PCB: 36.99$ on JLCPCB

==> total of 103$ USD (with shipping)



**Total time spent: 3 hours**

# Day 13: Organise workspace & create README.md


Update image in Images workspace + put cad in /cad folder
I made README: 

About software part:
Actually I would like flashing QLC+ on this processing unit but after I can flash lot of soft on it

QLCPlus link: https://github.com/mcallegari/qlcplus/

**Total time spent: 0.5 hours**

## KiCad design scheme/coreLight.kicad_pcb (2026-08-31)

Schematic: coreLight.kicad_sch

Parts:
BT1: Battery; BatteryHolder_Keystone_3000_1x12mm
BZ1: Buzzer 3.3V; Buzzer_12x9.5RM7.6
C1, C4, C6, C9, C13, C16, C27, C29, C30, C31, C34, C36, C39, C42, C44, C46, C48, C50, C52, C54, C56, C58, C60, C62, C64, C66, C68, C69, C71, C72, C76, C78, C79: 100nF; C_0805_2012Metric
C2, C3, C32, C33: 22pF; C_0805_2012Metric
C5, C7, C8, C28, C35, C40, C41, C43, C45, C47, C49, C51, C53, C55, C57, C59, C61, C63, C65, C75, C77: 4.7µF; C_0805_2012Metric
C12, C81: 1uF; C_0805_2012Metric
C26, C70: 10uF; C_0805_2012Metric
C37, C67: 4.7uF; C_0805_2012Metric
C73, C74: 10nF; C_0805_2012Metric
C80: 2.2nF; C_0805_2012Metric
D4: D_TVS_Dual_AAC; D_SOT-23
D17: 1N5819; D_DO-41_SOD81_P10.16mm_Horizontal
D31, D33, D34, D35, D36, D37, D38, D39, D40, D41, D42, D43, D44: SM712; D_SOT-23
D32: 1N4148; D_DO-35_SOD27_P7.62mm_Horizontal
D47, D48, D49, D50, D51, D52, D53: LED; LED_0805_2012Metric
F2: Fuse 3-5A; Fuse_1812_4532Metric_Pad1.30x3.40mm_HandSolder
FB1, FB3: FerriteBead; C_0805_2012Metric
J1: Micro_SD_Card; microSD_HC_Hirose_DM3D-SF
J3: RJ45_Hanrun_HR911105A_Horizontal
J5, J6, J21, J23, J24, J25, J26, J27, J28, J29, J30, J31, J32: Con DMX; JST_XH_B3B-XH-A_1x03_P2.50mm_Vertical
J16: USB_C_Receptacle_USB2.0_16P; USB_C_Receptacle_HRO_TYPE-C-31-M-12
J17: 24v in; TerminalBlock_Phoenix_MKDS-1,5-2-5.08_1x02_P5.08mm_Horizont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
J18: FAN; JST_XH_B2B-XH-A_1x02_P2.50mm_Vertical
J19: SWD; JST_XH_B5B-XH-A_1x05_P2.50mm_Vertical
J20: UART; JST_XH_B4B-XH-A_1x04_P2.50mm_Vertical
J22: LTC IN; Jack_3.5mm_Ledino_KB3SPRS_Horizontal
Q14, Q16: MOSFET; TO-252-3_TabPin2
Q15: 2N7002/AOD; Q_SOT-23
R1, R4, R5, R6, R9, R42, R58, R74, R80, R82, R83, R84, R88, R89, R90: 10k; R_0805_2012Metric
R2, R3, R10, R11, R12, R13, R14, R15, R16: 330R; R_0805_2012Metric
R7: 12.1k; R_0805_2012Metric
R8: 12.4k; R_0805_2012Metric
R41: 1k; R_0805_2012Metric
R43, R44: 5.1K; R_0805_2012Metric
R45: 10-50mΩ; R_0805_2012Metric
R59, R72, R75, R85, R86: 100k; R_0805_2012Metric
R73: 52.3k; R_0805_2012Metric
R76: 100R; R_0805_2012Metric
R87: 120R; R_0805_2012Metric
SW1: BOOT; SW_Push_1P1T_NO_6x6mm_H9.5mm
SW2: EC11 with BTN; RotaryEncoder_Alps_EC11E-Switch_Vertical_H20mm
SW3, SW4, SW5, SW6, SW7: SW_Push; SW_Push_1P1T_NO_6x6mm_H9.5mm
U2: IS42S16400J-xC; TSOP-II-54_22.2x10.16mm_P0.8mm
U3: W25Q128JVS; SOIC-8_5.23x5.23mm_P1.27mm
U4: NUCLEO144-H743ZI; LQFP-144-1EP_20x20mm_P0.5mm_EP6.5x6.5mm
U5: W5500; LQFP-48_7x7mm_P0.5mm
U6, U7, U8, U9, U10, U11, U12, U13, U14, U15, U16, U17, U18, U27: MAX3485; SOIC-8_3.9x4.9mm_P1.27mm
U19: DS3231M; SOIC-16W_7.5x10.3mm_P1.27mm
U20: LM2596S-ADJ 5V; TO-263-5_TabPin3
U21: AP2112K-3.3; SOT-23-5
U22: INA226; VSSOP-10_3x3mm_P0.5mm
U23, U24: TMP117xxDRV; WSON-6-1EP_2x2mm_P0.65mm_EP1x1.6mm
U25: CD74HC4067M; SOIC-24W_7.5x15.4mm_P1.27mm
U26: USBLC6-2SC6; SOT-23-6
Y1, Y3: Crystal 25MHz; Crystal_SMD_3225-4Pin_3.2x2.5mm

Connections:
+3.3V: BZ1.1 (+), C1.2, C4.1, C5.1, C6.1, C7.1, C8.1, C9.1, C26.2, C27.2, C28.1, C29.1, C30.1, C31.1, C34.1, C37.2, C39.1, C40.1, C41.1, C42.1, C43.1, C44.1, C45.1, C46.1, C47.1, C48.1, C49.1, C50.1, C51.1, C52.1, C53.1, C54.1, C55.1, C56.1, C57.1, C58.1, C59.1, C60.1, C61.1, C62.1, C63.1, C64.1, C67.1, C68.1, C69.1, C70.1, C71.1, C75.1, C76.1, C77.1, C78.1, C79.1, D32.1 (K), FB1.2, FB3.2, J1.4 (VDD), J3.4 (TCT), J3.5 (RCT), J19.1, J20.1, R1.1, R10.1, R11.1, R12.1, R13.1, R14.1, R15.2, R16.2, R42.2, R58.2, R89.2, R90.2, SW1.1, U2.1 (VDD), U2.3 (VDDQ), U2.9 (VDDQ), U2.14 (VDD), U2.27 (VDD), U2.43 (VDDQ), U2.49 (VDDQ), U3.8 (VCC), U4.5 (VDD), U4.33 (VBAT), U5.4 (AVDD), U5.8 (AVDD), U5.11 (AVDD), U5.15 (AVDD), U5.17 (AVDD), U5.21 (AVDD), U5.28 (VDD), U6.8 (VCC), U7.8 (VCC), U8.8 (VCC), U9.8 (VCC), U10.8 (VCC), U11.8 (VCC), U12.8 (VCC), U13.8 (VCC), U14.8 (VCC), U15.8 (VCC), U16.8 (VCC), U17.8 (VCC), U18.8 (VCC), U19.2 (VCC), U22.6 (VS), U23.5 (V+), U24.4 (ADD0), U24.5 (V+), U25.24 (VCC), U27.8 (VCC)
+5V: C65.1, C66.1, R73.2, R75.1, U20.2 (OUT), U21.1 (VIN)
+24V_LOAD: C35.1, C36.1, J18.1, R45.2, R72.2, U20.1 (VIN), U22.9 (Vin-)
+24V_SAFE: Q14.2 (S), R45.1, U22.8 (Vbus), U22.10 (Vin+)
BTN_1: SW3.1, U4.47 (PE3)
BTN_2: SW4.1, U4.48 (PE4)
BTN_3: SW7.1, U4.50 (PE5)
BTN_4: SW6.1, U4.62 (PE6)
BTN_5: SW5.1, U4.23 (BT/PC13)
BUZZER_CTRL: R41.1, U4.96 (PB1)
DMX_EN_1: U4.105 (USB_ID/PA10), U18.2 (~RE), U18.3 (DE)
DMX_EN_2: U4.17 (PA15), U17.2 (~RE), U17.3 (DE)
DMX_EN_3: U4.40 (PD3), U8.2 (~RE), U8.3 (DE)
DMX_EN_4: U4.39 (PD4), U11.2 (~RE), U11.3 (DE)
DMX_EN_5: U4.43 (PD6), U14.2 (~RE), U14.3 (DE)
DMX_EN_6: U4.45 (PD7), U16.2 (~RE), U16.3 (DE)
DMX_EN_7: U4.63 (PG9), U7.2 (~RE), U7.3 (DE)
DMX_EN_8: U4.66 (PG10), U10.2 (~RE), U10.3 (DE)
DMX_EN_9: U4.133 (PG14), U13.2 (~RE), U13.3 (DE)
DMX_EN_10: U4.103 (SWO/PB3), U15.2 (~RE), U15.3 (DE)
DMX_EN_11: U4.99 (PB4), U6.2 (~RE), U6.3 (DE)
DMX_EN_12: U4.101 (PB5), U9.2 (~RE), U9.3 (DE)
DMX_EN_13: U4.77 (PB9), U12.2 (~RE), U12.3 (DE)
DMX_RX_1: U4.98 (PB15), U18.1 (RO)
DMX_RX_2: U4.109 (PA3), U17.1 (RO)
DMX_RX_3: U4.90 (PB11), U8.1 (RO)
DMX_RX_4: U4.30 (ETH_MDIO/PA1), U11.1 (RO)
DMX_RX_5: U4.88 (PB12), U14.1 (RO)
DMX_RX_6: U16.1 (RO), U25.8 (I1)
DMX_RX_7: U7.1 (RO), U25.6 (I3)
DMX_RX_8: U10.1 (RO), U25.4 (I5)
DMX_RX_9: U13.1 (RO), U25.2 (I7)
DMX_RX_10: U15.1 (RO), U25.22 (I9)
DMX_RX_11: U6.1 (RO), U25.20 (I11)
DMX_RX_12: U9.1 (RO), U25.18 (I13)
DMX_RX_13: U12.1 (RO), U25.16 (I15)
DMX_TX_1: U4.100 (LD3/PB14), U18.4 (DI)
DMX_TX_2: U4.107 (PA2), U17.4 (DI)
DMX_TX_3: U4.97 (PB10), U8.4 (DI)
DMX_TX_4: U4.28 (ETH_REF_CLK/PA0), U11.4 (DI)
DMX_TX_5: U4.89 (PB6), U14.4 (DI)
DMX_TX_6: U16.4 (DI), U25.9 (I0)
DMX_TX_7: U7.4 (DI), U25.7 (I2)
DMX_TX_8: U10.4 (DI), U25.5 (I4)
DMX_TX_9: U13.4 (DI), U25.3 (I6)
DMX_TX_10: U15.4 (DI), U25.23 (I8)
DMX_TX_11: U6.4 (DI), U25.21 (I10)
DMX_TX_12: U9.4 (DI), U25.19 (I12)
DMX_TX_13: U12.4 (DI), U25.17 (I14)
ENC_A: C73.1, R42.1, SW2.A, U4.25 (RTC_CRYSTAL/PC14)
ENC_B: C74.1, R58.1, SW2.B, U4.27 (RTC_CRYSTAL/PC15)
ENC_BTN: SW2.S1
ETH_CS: U4.41 (PD5), U5.32 (~SCS)
ETH_INT: U4.65 (PG12), U5.36 (~INT)
ETH_MISO: U4.35 (PC2), U5.34 (MISO)
ETH_MOSI: U4.36 (ETH_MDC/PC1), U5.35 (MOSI)
ETH_RST: U4.70 (PG11/ETH_TX_EN), U5.37 (~RST)
ETH_SCK: U4.102 (ETH_TXD1/PB13), U5.33 (SCLK)
FAN_PWM: R76.2, R86.2, U4.94 (PB2)
FMC_A0: U2.23 (A0), U4.53 (PF0)
FMC_A1: U2.24 (A1), U4.51 (PF1)
FMC_A2: U2.25 (A2), U4.52 (PF2)
FMC_A3: U2.26 (A3), U4.130 (PF3)
FMC_A4: U2.29 (A4), U4.110 (PF4)
FMC_A5: U2.30 (A5), U4.108 (PF5)
FMC_A6: U2.31 (A6), U4.131 (PF12)
FMC_A7: U2.32 (A7), U4.129 (PF13)
FMC_A8: U2.33 (A8), U4.122 (PF14)
FMC_A9: U2.34 (A9), U4.132 (PF15)
FMC_A10: U2.22 (A10), U4.59 (PG0)
FMC_A11: U2.35 (A11), U4.58 (PG1)
FMC_BA0: U2.20 (BA0), U4.141 (PG4)
FMC_BA1: U2.21 (BA1), U4.140 (PG5)
FMC_D0: U2.2 (DQ0), U4.118 (PD14)
FMC_D1: U2.4 (DQ1), U4.120 (PD15)
FMC_D2: U2.5 (DQ2), U4.57 (PD0)
FMC_D3: U2.7 (DQ3), U4.55 (PD1)
FMC_D4: U2.8 (DQ4), U4.116 (PE7)
FMC_D5: U2.10 (DQ5), U4.112 (PE8)
FMC_D6: U2.11 (DQ6), U4.124 (PE9)
FMC_D7: U2.13 (DQ7), U4.119 (PE10)
FMC_D8: U2.42 (DQ8), U4.128 (PE11)
FMC_D9: U2.44 (DQ9), U4.121 (PE12)
FMC_D10: U2.45 (DQ10), U4.127 (PE13)
FMC_D11: U2.47 (DQ11), U4.123 (PE14)
FMC_D12: U2.48 (DQ12), U4.125 (PE15)
FMC_D13: U2.50 (DQ13), U4.82 (STLINK_TX/PD8)
FMC_D14: U2.51 (DQ14), U4.69 (STLINK_RX/PD9)
FMC_D15: U2.53 (DQ15), U4.137 (PD10)
FMC_NBL0: U2.15 (LDQM), U4.136 (PE0)
FMC_NBL1: U2.39 (UDQM), U4.61 (PE1)
FMC_SDCAS: U2.17 (~CAS), U4.64 (PG15)
FMC_SDCKE0: U2.37 (CKE), U4.37 (PC3)
FMC_SDCLK: U2.38 (CLK), U4.138 (PG8)
FMC_SDNE0: U2.19 (~CS), U4.106 (ETH_RXD0/PC4)
FMC_SDNWE: U2.16 (~WE), U4.38 (PC0)
FMC_SDRAS: U2.18 (~RAS), U4.134 (PF11)
GND: BT1.2 (-), C1.1, C2.1, C3.2, C4.2, C5.2, C6.2, C7.2, C8.2, C9.2, C12.2, C13.2, C16.1, C26.1, C27.1, C28.2, C29.2, C30.2, C31.2, C32.1, C33.2, C34.2, C35.2, C36.2, C37.1, C39.2, C40.2, C41.2, C42.2, C43.2, C44.2, C45.2, C46.2, C47.2, C48.2, C49.2, C50.2, C51.2, C52.2, C53.2, C54.2, C55.2, C56.2, C57.2, C58.2, C59.2, C60.2, C61.2, C62.2, C63.2, C64.2, C65.2, C66.2, C67.2, C68.2, C69.2, C70.2, C71.2, C72.1, C73.2, C74.2, C75.2, C76.2, C77.2, C78.2, C79.2, C80.1, C81.2, D4.3 (common), D31.3 (common), D33.3 (common), D34.3 (common), D35.3 (common), D36.3 (common), D37.3 (common), D38.3 (common), D39.3 (common), D40.3 (common), D41.3 (common), D42.3 (common), D43.3 (common), D44.3 (common), J1.6 (VSS), J1.9 (SHIELD), J3.10, J3.11, J5.1, J6.1, J16.A1 (GND), J16.A12 (GND), J16.B1 (GND), J16.B12 (GND), J16.S1 (SHIELD), J17.2, J19.3, J20.4, J21.1, J22.S, J23.1, J24.1, J25.1, J26.1, J27.1, J28.1, J29.1, J30.1, J31.1, J32.1, Q15.3 (D), Q16.2 (S), R4.1, R5.1, R6.1, R7.2, R8.2, R9.1, R43.2, R44.2, R59.2, R74.1, R85.1, R86.1, SW2.C, SW2.S2, SW3.2, SW4.2, SW5.2, SW6.2, SW7.2, U2.6 (GNDQ), U2.12 (GNDQ), U2.28 (GND), U2.41 (GND), U2.46 (GNDQ), U2.52 (GNDQ), U2.54 (GND), U3.4 (GND), U4.8 (GND), U4.19 (GND), U4.20 (GND), U4.22 (GND), U4.49 (GND), U4.60 (GND), U4.71 (GND), U4.72 (GND), U4.81 (GND), U4.92 (GND), U4.104 (AGND), U4.111 (GND), U4.126 (GND), U4.135 (GND), U4.143 (GND), U4.144 (GND), U5.3 (AGND), U5.9 (AGND), U5.14 (AGND), U5.16 (AGND), U5.19 (AGND), U5.29 (GND), U5.48 (AGND), U6.5 (GND), U7.5 (GND), U8.5 (GND), U9.5 (GND), U11.5 (GND), U12.5 (GND), U13.5 (GND), U14.5 (GND), U15.5 (GND), U16.5 (GND), U17.5 (GND), U18.5 (GND), U19.5 (GND), U19.6 (GND), U19.7 (GND), U19.8 (GND), U19.9 (GND), U19.10 (GND), U19.11 (GND), U19.12 (GND), U19.13 (GND), U20.3 (GND), U21.2 (GND), U22.1 (A1), U22.2 (A0), U22.7 (GND), U23.2 (GND), U23.4 (ADD0), U24.2 (GND), U25.12 (GND), U25.15 (~E), U26.2 (GND), U27.2 (~RE), U27.3 (DE), U27.4 (DI), U27.5 (GND)
I2C_SCL: U4.75 (PB8), U19.16 (SCL), U22.5 (SCL), U23.1 (SCL), U24.1 (SCL)
I2C_SDA: U4.21 (LD2/PB7), U19.15 (SDA), U22.4 (SDA), U23.6 (SDA), U24.6 (SDA)
LED_STATUS1: D53.1 (K), U4.117 (PD11)
LED_STATUS2: D51.1 (K), U4.115 (PD12)
LED_STATUS3: D52.1 (K), U4.113 (PD13)
LED_STATUS4: D49.1 (K), U4.42 (PG2)
LED_STATUS5: D50.1 (K), U4.44 (PG3)
LED_STATUS6: D48.1 (K), U4.139 (PG7/USB_GPIO_IN)
LED_STATUS7: D47.1 (K), U4.93 (USB_VBUS/PA9)
LTC_RX: U4.87 (ETH_CRS_DV/PA7), U27.1 (RO)
MUX_S0: U4.32 (PA4), U25.10 (S0)
MUX_S1: U4.83 (PA5), U25.11 (S1)
MUX_S2: U4.85 (PA6), U25.14 (S2)
MUX_S3: U4.34 (PB0), U25.13 (S3)
unnamed: BT1.1 (+), D17.2 (A)
unnamed: BZ1.2 (-), D32.2 (A), Q16.3 (D)
unnamed: D4.1 (A1), J22.T, R87.1, U27.6 (A)
unnamed: D4.2 (A2), J22.R, R87.2, U27.7 (B)
unnamed: D17.1 (K), U19.14 (VBAT)
unnamed: D31.1 (A1), J6.3, U18.6 (A)
unnamed: D31.2 (A2), J6.2, U18.7 (B)
unnamed: D33.1 (A1), J5.3, U17.6 (A)
unnamed: D33.2 (A2), J5.2, U17.7 (B)
unnamed: D34.1 (A1), J21.3, U8.6 (A)
unnamed: D34.2 (A2), J21.2, U8.7 (B)
unnamed: D35.1 (A1), J23.3, U11.6 (A)
unnamed: D35.2 (A2), J23.2, U11.7 (B)
unnamed: D36.1 (A1), J24.3, U14.6 (A)
unnamed: D36.2 (A2), J24.2, U14.7 (B)
unnamed: D37.1 (A1), J25.3, U16.6 (A)
unnamed: D37.2 (A2), J25.2, U16.7 (B)
unnamed: D38.1 (A1), J26.3, U7.6 (A)
unnamed: D38.2 (A2), J26.2, U7.7 (B)
unnamed: D39.1 (A1), J27.3, U10.6 (A)
unnamed: D39.2 (A2), J27.2, U10.7 (B)
unnamed: D40.1 (A1), J28.3, U13.6 (A)
unnamed: D40.2 (A2), J28.2, U13.7 (B)
unnamed: D41.1 (A1), J29.3, U15.6 (A)
unnamed: D41.2 (A2), J29.2, U15.7 (B)
unnamed: D42.1 (A1), J30.3, U6.6 (A)
unnamed: D42.2 (A2), J30.2, U6.7 (B)
unnamed: D43.1 (A1), J31.3, U9.6 (A)
unnamed: D43.2 (A2), J31.2, U9.7 (B)
unnamed: D44.1 (A1), J32.3, U12.6 (A)
unnamed: D44.2 (A2), J32.2, U12.7 (B)
unnamed: D47.2 (A), R16.1
unnamed: D48.2 (A), R15.1
unnamed: D49.2 (A), R13.2
unnamed: D50.2 (A), R14.2
unnamed: D51.2 (A), R11.2
unnamed: D52.2 (A), R12.2
unnamed: D53.2 (A), R10.2
unnamed: J1.3 (CMD), R88.2
unnamed: J1.7 (DAT0), R83.2
unnamed: J1.8 (DAT1), R84.2
unnamed: J1.1 (DAT2), R80.2
unnamed: J1.2 (DAT3/CD), R82.2
unnamed: J3.9, R2.1
unnamed: J3.12, R3.1
unnamed: J3.3 (RD+), U5.5 (RXN)
unnamed: J3.6 (RD-), U5.6 (RXP)
unnamed: J3.1 (TD+), U5.1 (TXN)
unnamed: J3.2 (TD-), U5.2 (TXP)
unnamed: J16.A5 (CC1), R44.1
unnamed: J16.B5 (CC2), R43.1
unnamed: J16.A6 (D+), J16.B6 (D+), U26.1 (I/O1)
unnamed: J16.A7 (D-), J16.B7 (D-), U26.3 (I/O2)
unnamed: F2.2, J17.1
unnamed: J18.2, Q15.2 (S)
unnamed: F2.1, Q14.3 (D)
unnamed: Q14.1 (G), R85.2
unnamed: Q15.1 (G), R76.1
unnamed: Q16.1 (G), R41.2, R59.1
unnamed: C12.1, C13.1, FB3.1, U4.79 (AVDD)
unnamed: C3.1, U4.29 (PH0), Y1.2
unnamed: C2.2, U4.31 (PH1), Y1.1
unnamed: R9.2, SW1.2, U4.7 (~BOOT0)
unnamed: R1.2, U4.14 (~RST)
unnamed: C81.1, U5.22 (1V2O)
unnamed: R2.2, U5.27 (ACTLED)
unnamed: R7.1, U5.10 (EXRES1)
unnamed: R3.2, U5.25 (LINKLED)
unnamed: R4.2, U5.45 (PMODE0)
unnamed: R5.2, U5.44 (PMODE1)
unnamed: R6.2, U5.43 (PMODE2)
unnamed: C80.2, U5.20 (TOCAP)
unnamed: R8.1, U5.18 (VBG)
unnamed: C33.1, U5.30 (XI/CLKIN), Y3.2
unnamed: C32.2, U5.31 (XO), Y3.1
unnamed: R89.1, U19.3 (~INT/SQW)
unnamed: R90.1, U19.4 (~RST)
unnamed: R73.1, R74.2, U20.4 (FB)
unnamed: R72.1, U20.5 (~ON/OFF)
unnamed: R75.2, U21.3 (EN)
unnamed: C16.2, FB1.1, U21.5 (VOUT)
QSPI_BK1_IO0: U3.5 (DI(IO0)), U4.54 (PF8)
QSPI_BK1_IO1: U3.2 (DO(IO1)), U4.56 (PF9)
QSPI_BK1_IO2: U3.3 (IO2), U4.46 (PE2)
QSPI_BK1_IO3: U3.7 (IO3), U4.9 (PF6)
QSPI_BK1_NCS: U3.1 (~CS), U4.142 (PG6/USB_GPIO_OUT)
QSPI_CLK: U3.6 (CLK), U4.114 (PF10)
SDIO_CK: J1.5 (CLK)
SDIO_CMD: R88.1, U4.4 (PD2)
SDIO_D0: R83.1, U4.74 (PC8)
SDIO_D1: R84.1, U4.73 (PC9)
SDIO_D2: R80.1, U4.1 (PC10)
SDIO_D3: R82.1, U4.2 (PC11)
SYS_RST: C72.2, J19.5
SYS_SWCLK: J19.2, U4.15 (TCK/PA14)
SYS_SWDIO: J19.4, U4.13 (TMS/PA13)
UART_RX: J20.3
UART_TX: J20.2
UART_TX_MULTIPLEXER: U4.76 (PC6), U25.1 (COM)
USB_DM: U4.86 (USB_DM/PA11), U26.4 (I/O2)
USB_DP: U4.84 (USB_DP/PA12), U26.6 (I/O1)
USB_VBUS: J16.A4 (VBUS), J16.A9 (VBUS), J16.B4 (VBUS), J16.B9 (VBUS), U26.5 (VBUS)

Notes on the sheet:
DEBUG
BRAIN
5V -> 3.3V
USB-C
DMX
MEMORY
LTC
MESURE ALIM
RTC
SENSORS
24V -> 5V
INPUT
ETHERNET
POWER

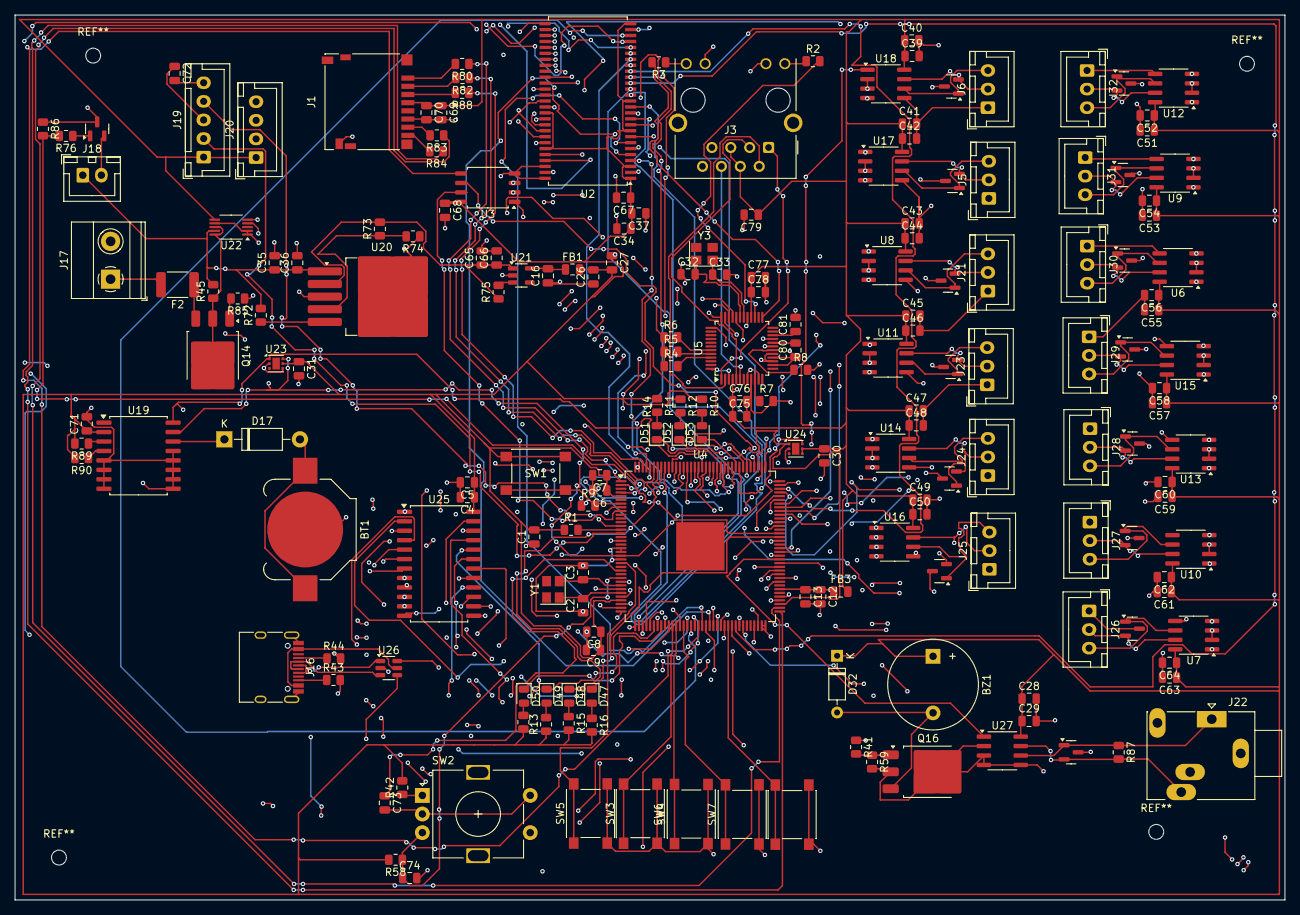
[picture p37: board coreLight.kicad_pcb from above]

Board: 4 copper layers, 170.7 x 119.0 mm, 192 parts (0 on the bottom side), 210 nets.
